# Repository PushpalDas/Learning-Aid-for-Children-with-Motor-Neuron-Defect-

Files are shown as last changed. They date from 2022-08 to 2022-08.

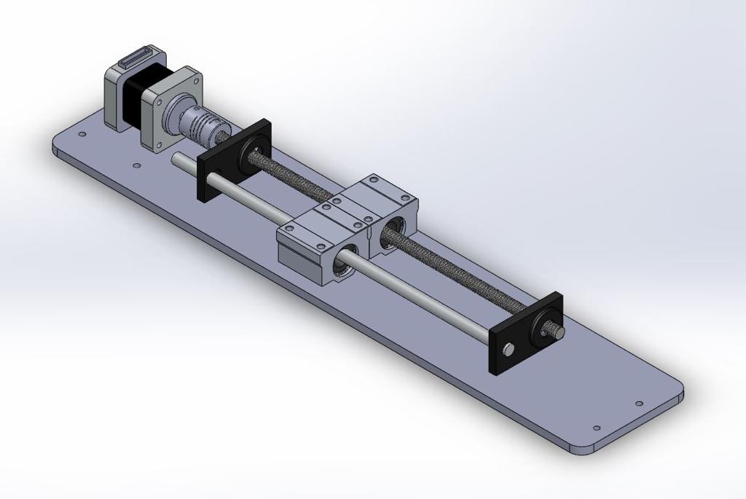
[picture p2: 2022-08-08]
IGES FILES/PHOTO-2022-01-13-23-20-01(11).jpg

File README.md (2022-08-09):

# Learning-Aid-for-Children-with-Motor-Neuron-Defect-
IoT wireless device to help a child write. [Arduino UNO, Stepper Motor, CNC, Bluetooth]

- [CNC Principle Demo - 1 (G-Code)](https://drive.google.com/file/d/1HKVO9aAVFRL1J57MTSo6BBsfIpMUPSG7/view?usp=sharing)
- [CNC Principle Demo - 2 (G-Code)](https://drive.google.com/file/d/1b37IInhLuG2e1p3JiCt-loMVagS_FO2U/view?usp=sharing)
- [CNC Principle Demo - 3 (G-Code)](https://drive.google.com/file/d/1SXlSRdfuU8yRSjG2uXwFo0BQJ_EmRbAA/view?usp=sharing)

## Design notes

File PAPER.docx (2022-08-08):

CNC-based Bluetooth-operated Learning Aid for Neurodiverse Children

P. Dasa, E. Vijayaragavan^b, A. Sarkar^c, S.A.R. Devalan^d, V.P. Dubeye, N. Aryan^f, R. S. Kumar^g A.D. Chatterjee^h

a Department of Electronics & Communication Engineering, SRM Institute of Science and Technology, Kattankulathur, Tamil Nadu 603203, India.

^b Department of Mechanical Engineering, SRM Institute of Science and Technology, Kattankulathur, Tamil Nadu 603203, India.

^c Department of Electronics & Telecommunication Engineering, Jadavpur University, Kolkata, West Bengal 700032, India.

^d Department of Mechanical Engineering, SRM Institute of Science and Technology, Kattankulathur, Tamil Nadu 603203, India.

e Department of Computer Science and Engineering, SRM Institute of Science and Technology, Kattankulathur, Tamil Nadu 603203, India.

^f Department of Computer Science and Engineering, SRM Institute of Science and Technology, Kattankulathur, Tamil Nadu 603203, India.

^g Department of Electronics & Communication Engineering, SRM Institute of Science and Technology, Kattankulathur, Tamil Nadu 603203, India.

^h Department of Computer Science and Engineering,Indian Institute of Engineering Science and Technology, Shibpur, Howrah, West Bengal 711103, India.

Abstract

The main objective of our team was to make an appealing learning assistant for kids who have neurodevelopmental conditions or impaired motor neuron abilities. Although many individuals with autism spectrum disorder today are able to speak, read, and live outside institutions, and some show a decrease in symptoms of the disorder by adulthood, for most of them it is difficult to work full-time or live independently. The common symptoms of such individuals are restricted social communication skills and repetitive sensory-motor behaviours. Our team surveyed some autistic care centres where the specialists said that even in the present age of digitally transforming world when it comes to the education of autistic children, a long-term effective output has not been observed and hence, it could not be predicted whether the kid is getting benefitted from the e-learning materials or not. Our vision was to make a device that will help such a child to learn writing through systematic repetition and stimulating audio-visual signals.

Acknowledgement

Our team would like to express our gratitude to SRM Institute of Science and Technology for the support and guidance . Our team would further express our gratitude to Dr E. Vijayaragavan, for the time, knowledge and constant encouragement she has lent us for making this project. We express our special thanks to Mr Shantanu Sinha, marketing consultant at TCS, for his genuine support and guidance in bringing the product to the market in the future.

Our team extends gratitude to Mrs Sampada Pachaury (https://www.linkedin.com/in/ACoAAAFvnSkB4kaB5wE9D-snUe5Wi9vhkcergZw), Mr Krishna Vedula (https://www.linkedin.com/in/ACoAAACEbJcBGnZhwTKeoU1zOtHO4xEXdkV7bjM) and Mr Aditya Bhatnagar for their diligent guidance and for their support during our research work with Indo Universal Collaboration for Engineering Education (IUCEE) (https://www.linkedin.com/company/indo-universal-collaboration-for-engineering-education/).

We used DigiKey Scheme-it, a free online schematic and diagramming tool, available at https://www.digikey.in/schemeit/home/ for the schematics provided in the paper. We used Inkscape v0.48.5, a free and open-source vector graphics editor primarily used for creating or editing vector graphics, for generating the g-codes. This was made possible by the MI Inkscape extension for GRBL firmware. From https://winder.github.io/ugs_website/ the controlling software for debugging and testing named “Universal Gcode Sender” was downloaded. A similar application for mobile was “G-Code2GRBL” and was downloaded from the Google play store. And most importantly, the GRBL firmware that was programmed into the microcontroller was downloaded from https://github.com/gnea/grbl/.

Content

Sl. No. | Topic | Page Number
1 | Introduction - Fig. 1: Prevalence of Autism Increased by 10%, to 1 in 54 Children by Southwest Autism Research & Resource Center - Fig. 2: Neurotypical Peers are Less Willing to Interact with Those with Autism based on Thin Slice Judgments - Fig. 3: Effect of a normal and regular classroom set up on the concentration and attentiveness of youngsters with autism spectrum disorder: an eye-tracking study | 4 4 5 5
2 | Background | 5

3

Design and Specification

a. Control and Power System
  i. Microcontroller-ATMEGA328P
  ii. CNC V3 shield
  iii. A4988 Stepper motor driver
  iv. NEMA 17 Stepper motor
  v. SG90 Micro Servo
  vi. HC-05 Bluetooth module
b. GRBL control code
c. G-code
d. Application software
- Fig. 4: (a) Logical block of the ATMEGA328P processor; (b) ATMEGA328P pin configuration
- Fig. 5: Pin-configuration of (a) CNC V3 shield; (b) stepper motor driver A4988
- Fig. 6: Configuration of the motors and respective motor drivers
- Fig. 7: (a) HC-05 Bluetooth module; (b) Connecting the Bluetooth module with the controller
- Fig. 8: Physical connections for the entire apparatus. It is to be noted that the CNC V3 shield is inserted onto the Arduino UNO board
- Fig. 9: How the g-code containing information of coordinates is transferred in the system
- Fig. 10: System architecture supporting the application
- Fig. 11: Sequence Diagram for the API
- Fig. 12: Flowchart describing the functioning of the application
- Fig. 13: All paired devices are displayed in the app being developed. Suppose a particular device should be connected, the relevant name must be clicked

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
4 | Implementation - Fig. 14: Perspective view of the model - Fig. 15: Two Dimensional Representation of the Model | 14 15 16
5 | Result and Evaluation - Fig. 16: Graphically Denoted No.of Letters v/s Time by the machine - Fig. 17: Graphically Denoted No.of Letters v/s Temperature of the machine in (Celsius) | 16 17 17
6 | Future Directions | 17
7 | Conclusion | 18
8 | Reflections | 18
9 | References | 19

Introduction

Autism is a term that is used to describe a particular group of people with specific neurodiverse conditions– conditions characterised by lack of ability to interact socially, communication problems and abnormal motor-neuron activity. Autistic Spectrum Disorder is observed in people around the world, irrespective of culture, background, race and ethnicity. “Spectrum” refers to the wide range and severity of symptoms shown by such individuals.

During a study period of 2009-2017, children most of the age from 3-17 were seen diagnosed with disabilities, which includes cerebral palsy, blindness, hyperactivity disorder, autism. Conditions are characterised by contrast in social interaction and communication. Over the study, it has been found that there are numerous causes. It can be due to genetic mutations, having an immediate family member who is autistic, metabolic imbalances, Exposure to heavy metals and environmental toxins, a history of viral infections, fatal exposure to the medications valproic or thalidomide. Subjects show snappy interhemispheric connections in the cerebral cortex.

Autistic kids might not get to the enlightening milestone like their fellow mates. They have difficulty sleeping, irregular food patterns and show signs of heightened anxiety. They often prefer a similar environment with a regular routine. They often show repetitive and restricted motor behaviour. The common motor deficit conditions seen in children with autism are hypotonia, which is characterised by poor muscle strength and disordered spinal reflexes, and motor apraxia, which is a defect in horizontal eye movement. Studies have also found deficits in overall fine motor gross motor development and locomotor skills for such children. These difficulties not only hamper their learning ability but also cause a great deal of anxiety to them.

Statistical data regarding the autistic population

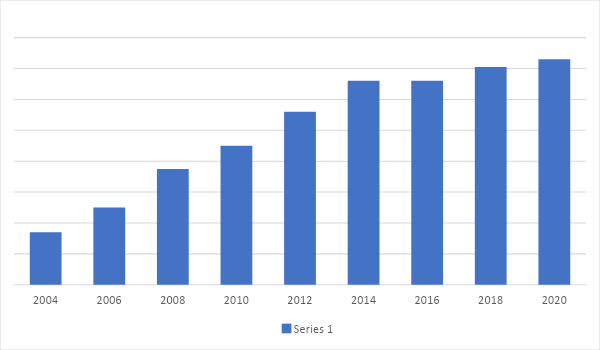
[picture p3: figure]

Fig. 1, Prevalence of Autism Increased by 10%, to 1 in 54 Children by Southwest Autism Research & Resource Center

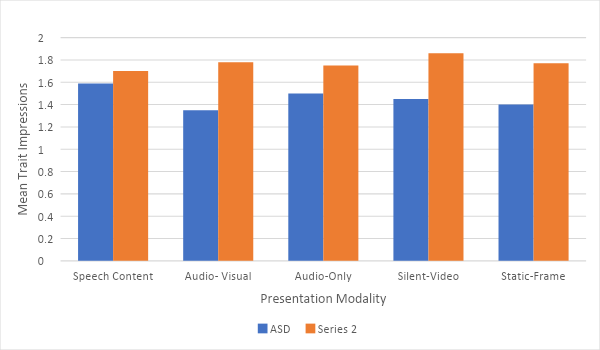
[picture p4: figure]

Fig. 2, Neurotypical Peers are Less Willing to Interact with Those with Autism based on Thin Slice Judgments

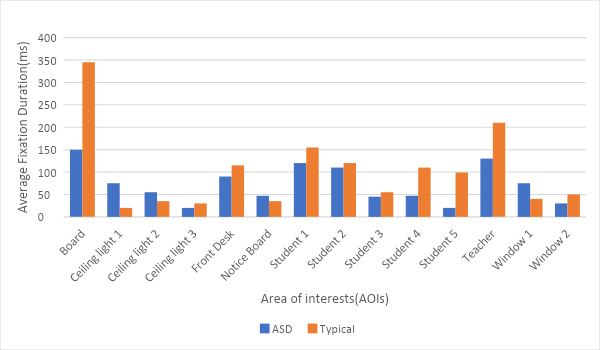
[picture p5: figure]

Fig. 3, Effect of a normal and regular classroom set up on the concentration and attentiveness of youngsters with autism spectrum disorder: an eye-tracking study

Background

The purpose of the present project is to create a link between play and physical therapy, resulting in therapy for such subjects who have writing problems from their very childhood–children who have difficulty distinguishing between 6 and 9, b and d, the alphabetical order, a step from our team to make the basics strong and solve the neurological problem in kids. From the research and surveys performed, it is understood that even in the present era of a digitally-transforming world, when it comes to e-learning platforms and persons with neurodevelopmental disabilities, a proper output is very difficult to ascertain. Given the plethora of application-based learning options, the child would still not receive physical help in actually writing what they have learnt. In special exams, such students would pronounce their answers and a helper would write for them.

Design and Specification

The aim of the project was to make the subject learn to write and correlate what they want to write and what their hand traces on paper by holding a robotic arm in the form of a mini CNC (Computer Numeric Control) machine. The device shall track the pattern of the letter and guide the user to move the hand in the right way to complete the pattern by interactive methods, which is basically the input given from the phone or computer in which the supporting application is installed. The application can be used easily by both the subject(person with a neurological disability) and their mentor. The principle of operation of the CNC machine is the movement of a structure about 3 degrees of freedom, namely the X, Y and Z axes, based on input fed through a computer. They are controlled by stepper motors which can be AC or DC operated. The operations and configurations of the motors like feed, speed, etc. are set with the help of coordinate-like codes.

Control and Power System

Microcontroller-ATMEGA328P

In today's world we have many controllers, so why ATMEGA328P?

ATMEGA328P is one of the most popular because it is cost-effective with exciting features in it. And so due to these features a controller like ATMEGA328P is used to develop Arduino boards. Features like, with a variation on power saving modes it can be used on mobile embedded systems, it has the RISC architecture, as a result of it the program executes quickly, has a timer, the watchdog timer to reset anytime under error on the system with just a human interface and so on. RISC is nothing but a reduced instruction set computer which is a type of architecture that uses a hugely optimised set of instructions than what is found in other architectures. ATMEGA is quite the same as any other microcontrollers in the market. And yes it is well known that there should be a set of instructions in the form of programs provided by us at the instant, without the program nothing is executing the way it should be. As already discussed, there should be a program present in the ATMEGA328 flash memory. This whole execution is done by the controller after the code is dumped and provides an appropriate response. This process is explained in the following steps,

- First step is listing out all the functions that the controller should execute. Functions in programming language can be run at IDE, now here we can use the Arduino IDE too to be discussed later. After the code we need to compile to look for errors.
- The IDE converts the compiled program to the HEX file. The HEX file constitutes the machine code that is executed or written in the controller flash memory.
- Choose the programming device (usually SPI programmer made for AVR controllers) which establishes communication between PC and ATMEGA328P. One can also program ATMEGA328P using the ARDUINO UNO board.
- After the execution all that is needed to do is, disconnecting the programmer, and connecting with the appropriate peripherals for the controller and running the system.

Features

1. The CPU used is an 8-bit AVR with a speed of 1MBPS for 1MHz .
2. There are a total 28 pins present.
3. Operating voltage ranges from +1.8 V to +5.5V.
4. There are 23 programmable I/O lines. For programming this controller, there are three types of communication interface, Master/Slave SPI Serial Interface(17,18,19 PINS).
5. Programmable Serial USART. This controller can be programmed using pins. Peripheral devices such as sensors, memory devices and servos are connected with the help of Two-wire Serial Interface pins.
6. It has ADC Module Of 6 channels, 10-bit resolution ADC. Timer module of two 8-bit counters with Separate Prescaler and compare mode. One 16-bit counter with Separate Prescaler,compare mode and capture mode.
7. There are a total of 1 analog comparator with 6 PWM channels.
8. External Oscillator with 0-4MHz in 1.8V to 5.5V, 0-10MHz in 2.7V to 5.5V, 0-20MHz in 4.5V to 5.5V and an internal oscillator with 8MHz Calibrated Internal Oscillator.
9. Program Memory Type is of flash memory with 32 kilobytes. RAM is 2kbytes Internal SRAM with an EEPROM of 1k bytes.
10. Programmable Watchdog Timer with Separate On-chip oscillator with program lock.
11. 6 major power save modules, Idle, ADC Noise Reduction, Power-save, Power-down, Standby and Extended Standby.
12. The operating temperature is -40°C to +105°C.

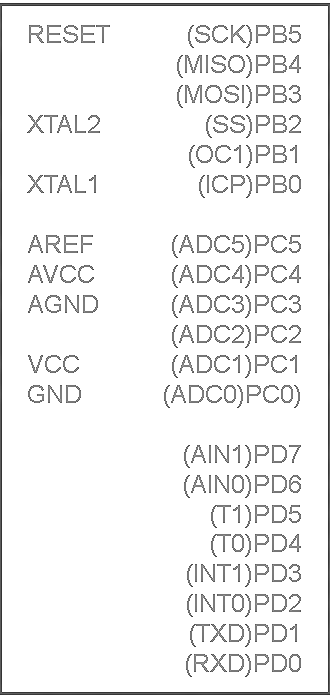
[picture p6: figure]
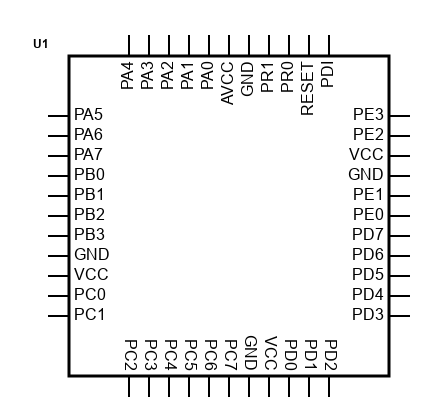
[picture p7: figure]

(a) (b)

Fig. 4, (a) Logical block of the ATMEGA328P processor; (b) ATMEGA328P pin configuration

CNC V3 shield

The CNC V3 shield is made particularly for Arduino based controllers which allows us to build such machines which are used to engrave, like a mini CNC, A 3D printer and so on. It just needs to be fitted on the top of the Arduino with no external wiring required. There are 4 slots for stepper motor drivers in the shield. It supports an input voltage of 12V to 36V. If an input of more than 36V is applied, it will damage the motor drivers.

A4988 Stepper motor drivers

The stepper motor driver, A4988, is a microstepping motor driver fully compatible with the CNC V3 shield. The bipolar stepper motors can be controlled in full, half, quarter, eighth and sixteenth step modes with the help of the drivers. They receive PWM signals from the Arduino and feed the required power according to the motors. The sixteenth step mode is used by inserting 3 jumper caps to cover M0, M1, M2 to improve the precision of the drawing.

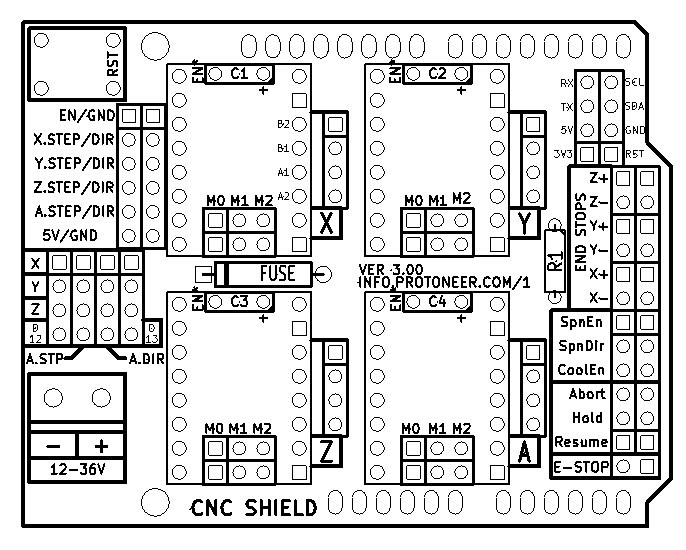
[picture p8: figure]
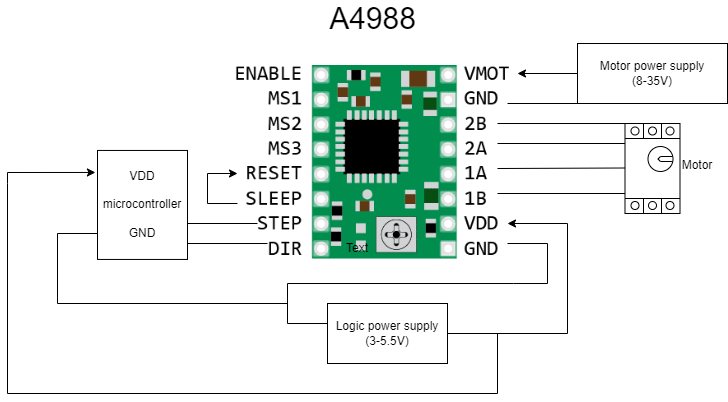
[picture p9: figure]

(a) (b)

Fig. 5, Pin-configuration of (a) CNC V3 shield; (b) stepper motor driver A4988

NEMA 17 Stepper motor

A stepper motor rotates by taking one step at a time, with the energy input given to it by DC and thereby, converts electrical energy into mechanical shaft rotation.

These motors are a vital part of the movement of the x and y axes in analog step values. “NEMA” is the measurement standard provided by the National Electrical Manufacturers Association. NEMA 17 stepper motors are used for this project. A heavier model was used because it could provide large enough torque to rotate the long and heavy metal shaft. For refined models with shorter axes lengths, smaller motors would be sufficient.

SG90 Microservo

Servo motor can be defined as a motor with a specific part, suitable for a closed-loop control system. Servo motors are used in robotics, CNC machining applications and so on. There is the control signal which is the input, it can be analog or digital, representing the final position for the shaft. An encoder serves the role of a sensor with speed and position.

The project deals with the principle of CNC machines and in such cases, nothing is better than the stepper motor to convert instructions into actions. Here the action is depicted as the up and down of the pen for writing and moving to the next consecutive letter.

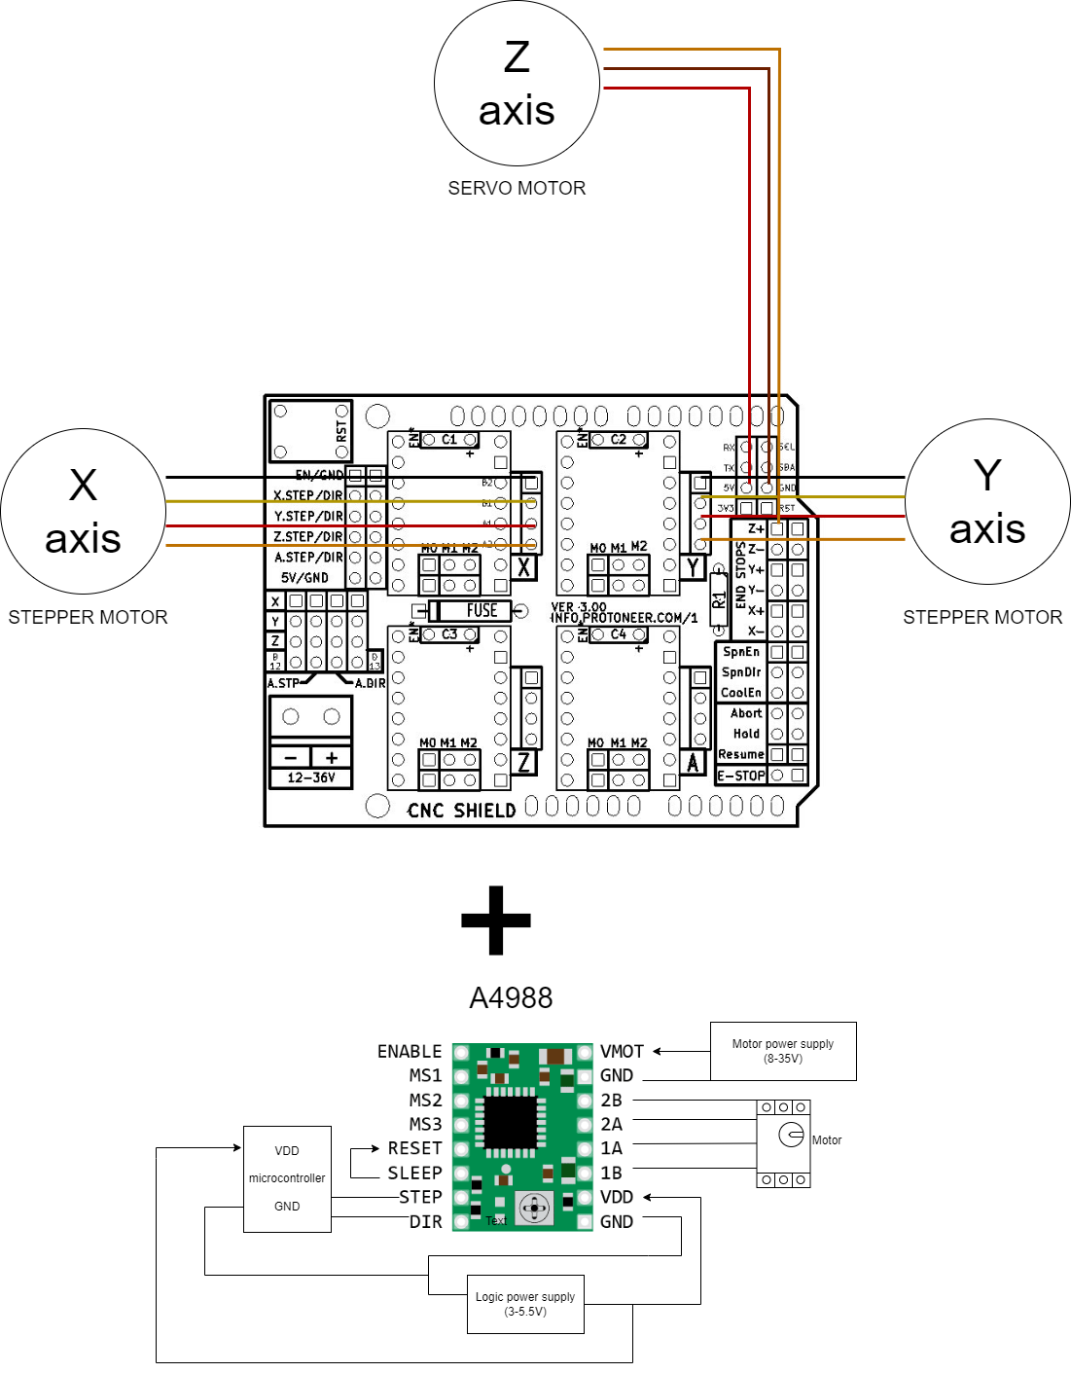
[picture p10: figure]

Fig. 6, Configuration of the motors and respective motor drivers

HC-05 Bluetooth module

Bluetooth HC-05 can be defined as serial communication to communicate with the world of electronics. Connecting to devices with short-range to exchange files. Just the way files are going to get exchanged in the project with a frequency band of 2,4 GHz. HC-05 has a transfer rate of 1Mbps within a range of 10 meters. Input power voltage is 4-6V with a baud rate of 9600, 19200, 38400, 57600, as selected by the user.

The pins of our interest are described below:

1. VCC - Pin which is connected to +5V power supply
2. Ground - Pin which is connected to the ground of the system
3. Tx (Transmitter) - Pin which transfers the wirelessly received data by UART method to the microcontroller
4. Rx (Receiver) - Pin which receives data to be broadcast from the microcontroller.

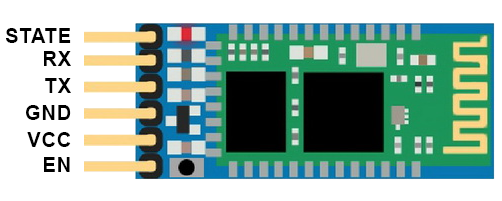
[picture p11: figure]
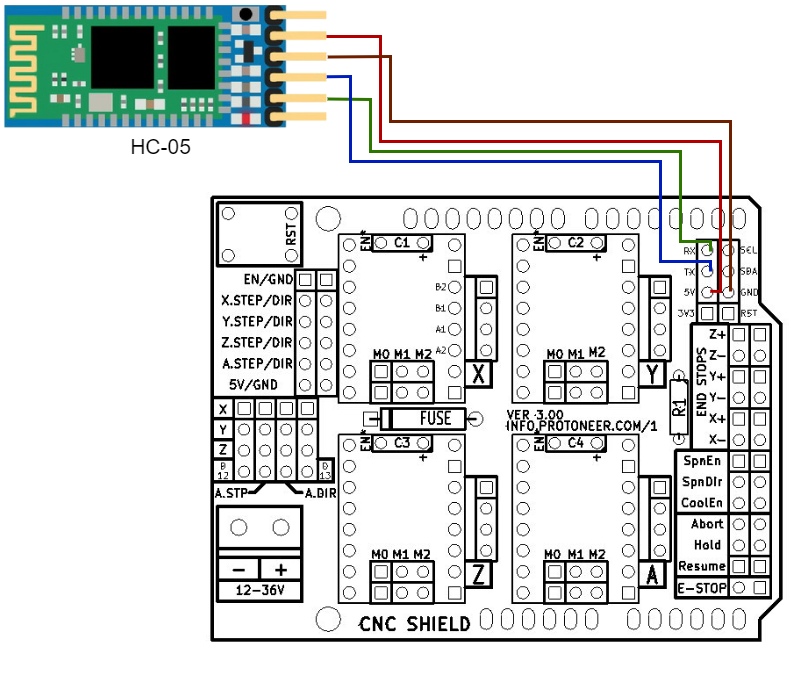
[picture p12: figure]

(a) (b)

Fig. 7, (a) HC-05 Bluetooth module; (b) Connecting the Bluetooth module with the controller

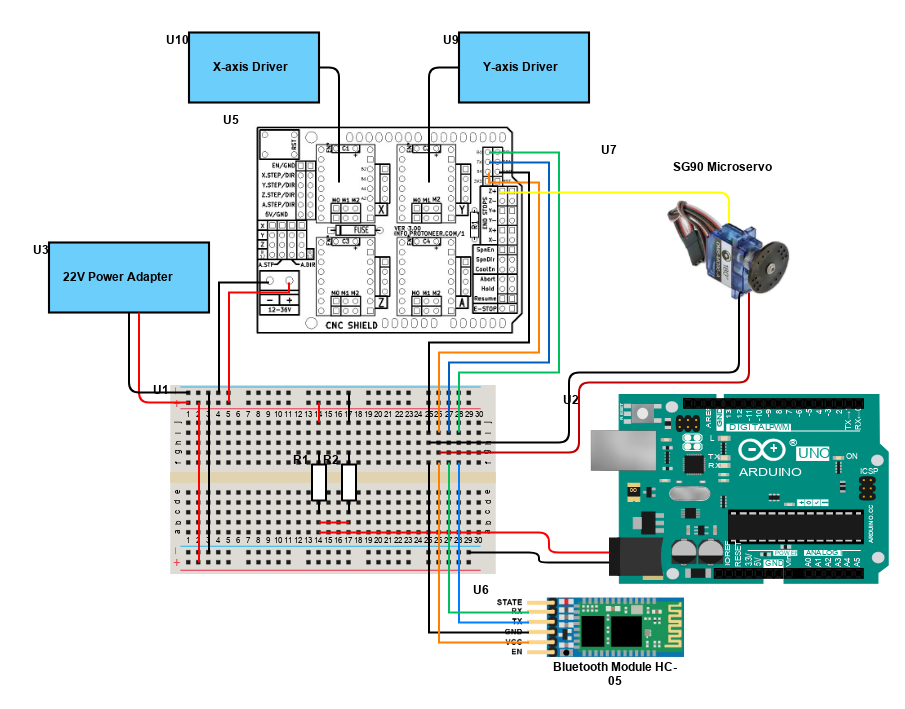
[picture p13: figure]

Fig. 8, Physical connections for the entire apparatus. It is to be noted that the CNC V3 shield is inserted onto the Arduino UNO board

GRBL control code

The shield is GRBL compatible. GRBL is an open-source firmware that is programmed into the Arduino and enables the g-code to be understood by the processor. For the intended purpose, the shield, before running with the stepper motors, needed to have the GRBL firmware installed in the Arduino’s memory. In simple terms , the GRBL uses the motion as the output through the motors via arduino and uses the G-code as an input to run through it.

G-code

G-code simply means “Geometric Code” that can be defined as the language of programming for a Computer Numerical Control machine, a CNC machine. This language is used to set the instruction to the machine to get operated. The speed and the path of the machine can be followed by the GRBL code. From 3D or 2D printing to manufacturing G-code runs the instruction layers formise a precise geometric shape in all dimensions.

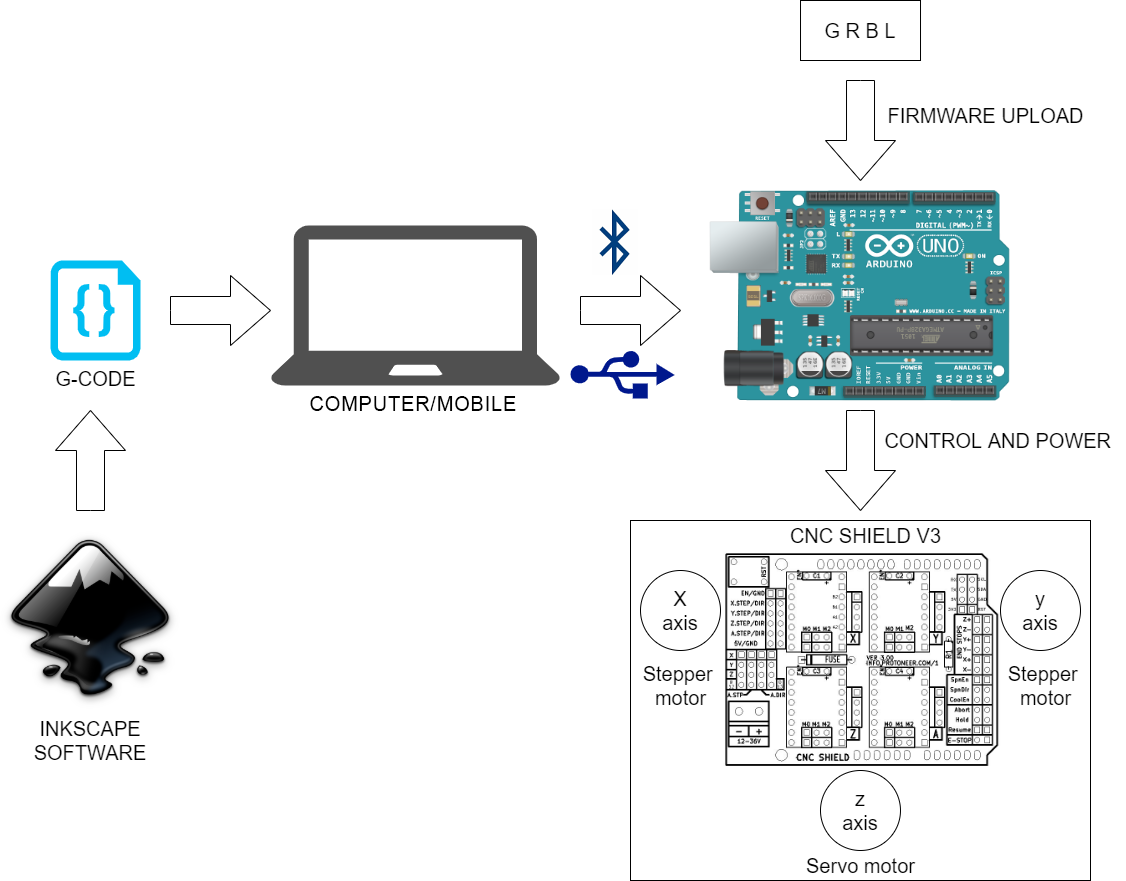
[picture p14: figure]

Fig. 9, How the g-code containing information of coordinates is transferred in the system

Application software

The hardware and its functioning will be controlled by an application running in the mobile phones. It has been assumed that during a teacher-student interaction the hardware is held by the individual with autism/cognitive disability while the mobile application is run by the teacher. A connection will be established over Bluetooth between the app and the actual hardware device. The mobile phone should have the capability to establish Bluetooth connections to use the app.

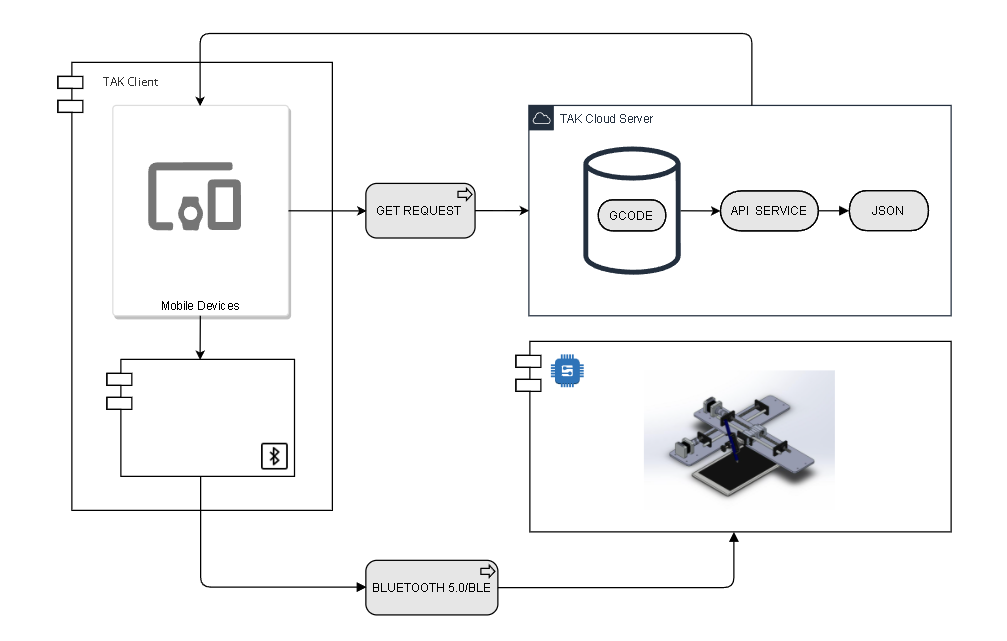
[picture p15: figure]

Fig. 10, System architecture supporting the application

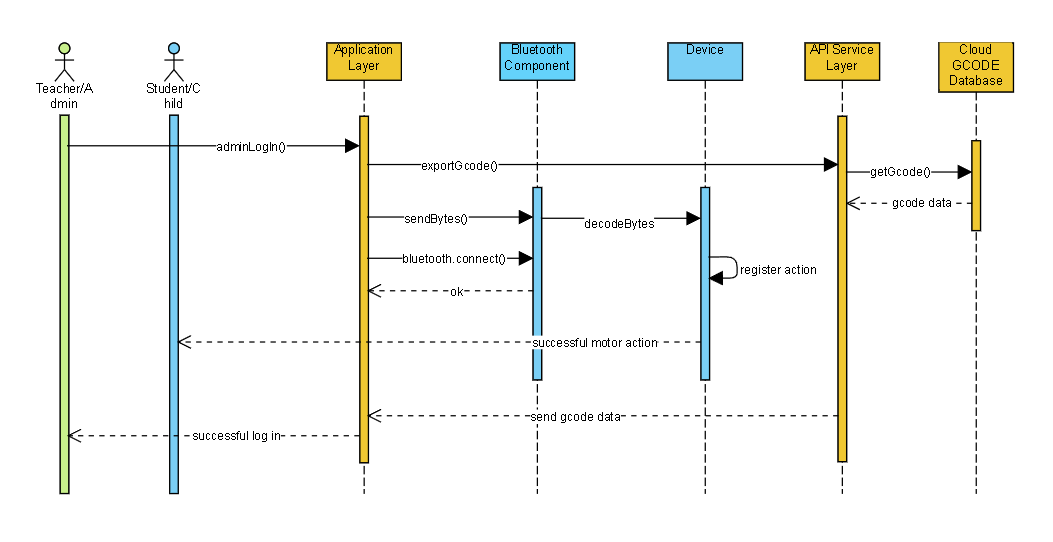
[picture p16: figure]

Fig. 11, Sequence Diagram for the API

Working algorithm, simulation

The official Google Developers site writes -

“To create a connection between two devices, you must implement both the server-side and client-side mechanisms because one device must open a server socket, and the other one must initiate the connection using the server device's MAC address. The server device and the client device each obtain the required Bluetooth socket (https://developer.android.com/reference/android/bluetooth/BluetoothSocket) in different ways. The server receives socket information when an incoming connection is accepted. The client provides socket information when it opens an RFCOMM channel to the server.

The server and client are considered connected to each other when they each have a connected BluetoothSocket on the same RFCOMM channel. At this point, each device can obtain input and output streams, and data transfer can begin”

The hardware Bluetooth device was first paired with the device. The mobile application then scanned through all paired devices to display the paired devices. The user needs to choose the hardware Bluetooth device from them. In the instrument, the hardware Bluetooth device is on the client-side and client-side mechanisms were pre-built. So only the server-side mechanisms need to be implemented,i.e, the mobile application.

Once the Bluetooth connection was established, the next task was to exchange data. In this scenario the exchange of data should be one-way, i.e, instruction signals should be sent from the device running the mobile application to the hardware Bluetooth device.

The hardware part of the product understands only G-code(just like a computer understands only machine language, so whatever high-level programs are written are ultimately converted to sequences 0s and 1s). So the job of the mobile application is to send the G-code corresponding to the relevant action.

The application will have sections like Alphabets, Digits, short sentences, almost everything you and I have been taught when we first went to school. Suppose a kid was learning about the alphabets and the teacher wanted the student to learn “A”. The user interface has buttons corresponding to all the alphabets. When the button displaying “A” was clicked, the corresponding g-code was sent to the hardware Bluetooth device. The Bluetooth accepts the data, decrypts it and a signal is sent to the hardware to trace the alphabet “A”.

The frontend interface will be intuitive and self-explanatory, so that it becomes easy to use and navigate. The home page of the application will be divided into well demarcated sections like alphabets, numbers, etc. Each section will have contents relevant to that topic. We will be using audio visual techniques to capture the attention of the audience. It is said one should pronounce what we read, because it helps in better retention. Thus pre-recorded voices reading aloud a text or an alphabet will be used for better engagement.

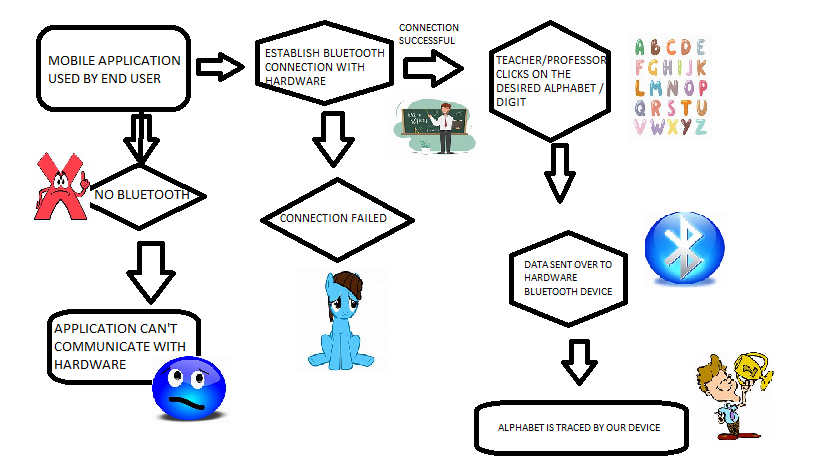
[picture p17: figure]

Fig. 12, Flowchart describing the functioning of the application

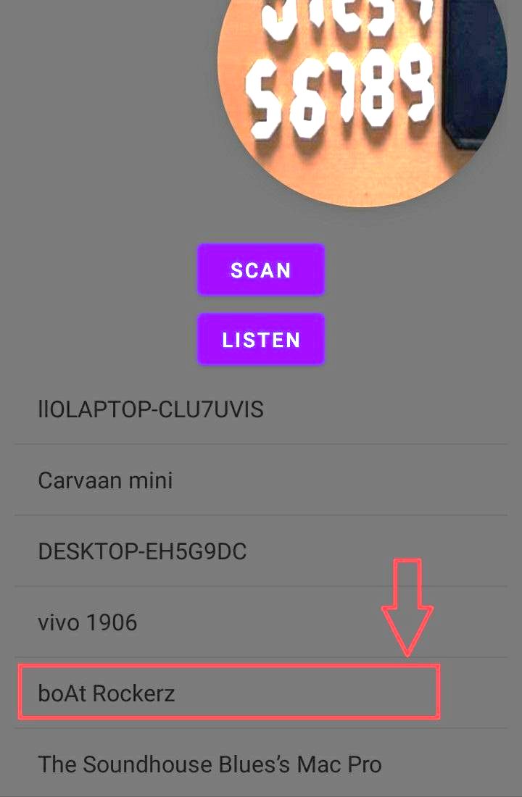
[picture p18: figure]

Fig. 13, All paired devices are displayed in the app being developed. Suppose a particular device should be connected, the relevant name must be clicked

Conclusion

While this is just a prototypic model of the software, there are a lot many improvements that can be added in course of time:

- A Local Area Network can be used for connecting the devices and exchanging data. This is more stable than Bluetooth, and also provides more flexibility. It is possible to control more devices from a single running instance of our application, unlike Bluetooth which allows one-to-one and not multiport connection.
- Speech recognition APIs like Google Translate can be used that allow users to write what they speak.
- The app can be made available in regional languages as well.

Implementation

For the apparatus, a wooden plank was used each for supporting the stepper motors for the x and y axes, along with the metallic shafts and gliders. The plank for the y-axis which held that of the x-axis was made slightly bigger in length to accommodate the microcontroller board and battery that would be fitted later on. Otherwise, both the axes looked similar. Each consisted of a NEMA 17 stepper motor fitted with a flexible coupling, THSL Lead Screw, EN31 Steel rod, linear motion ball bearing, linear bearing bush, radial bearings, block to hold the rod as well as bearings and the axial base. These two axes played a major role in the movement of the main module that is the pen stand. As for the z-axis which consists of a pen fitted to a vertically-moveable wooden block, it had two discrete states characterised by the position of the holder block that either stays down as the pen touches the paper or is lifted up such that there is no contact between the pen and the paper. The pen stand worked on the principle of linear motion provided by the motor and moved with the pen module attached to it. The stand was connected with the x-axis plank and consisted of a micro servo and moveable supportive parts for the rotatory motion of the pen. While the rotation of the motors for the x and y axes was analog–controlled by PWM signals from the respective motor driver (A4988) fitted to a CNC V3 shield atop the Arduino microcontroller board, the binary state of the SG-90 micro servo of the z-axis was controlled by a signal from the Z+ pin of the V3. As the Arduino UNO requires 5-12 volts DC and the CNC V3 requires up to 21 volts to supply the required power to the motors, we used a voltage divider setup using two 1 ohm-½ watt resistors organised on a breadboard. A 22V power adapter supplied regulated DC to the setup, from which 11V was fed to the Arduino UNO board from the node of the divided voltage while the original supply voltage was fed to the shield separately.

After receiving the feed execution command from the GRBL controller application through Bluetooth, the servo system drives each coordinate axis (feed mechanism) for the machine to move accurately in strict accordance with the command necessities and completes the process of the work. Throughout the displacement process, the detection feedback device quickly fed back the measured displacement numerical to the numerical control device for comparison with the command requirement, and then sent the compensation execution command to the servo system at rapid speed unless the measured value was consistent with the required command. There was a warning system to give safety reminders during various operations. In the method of axis displacement, if overtravel happened, the limiting device would send some over travel signals to the controller. Meanwhile, the numerical control system sent alarm signals through the execution and would send stop execution commands to the feed servo system to implement over travel protection. The writing machine works on this principle with the help of g-code as well as the direction of axes.

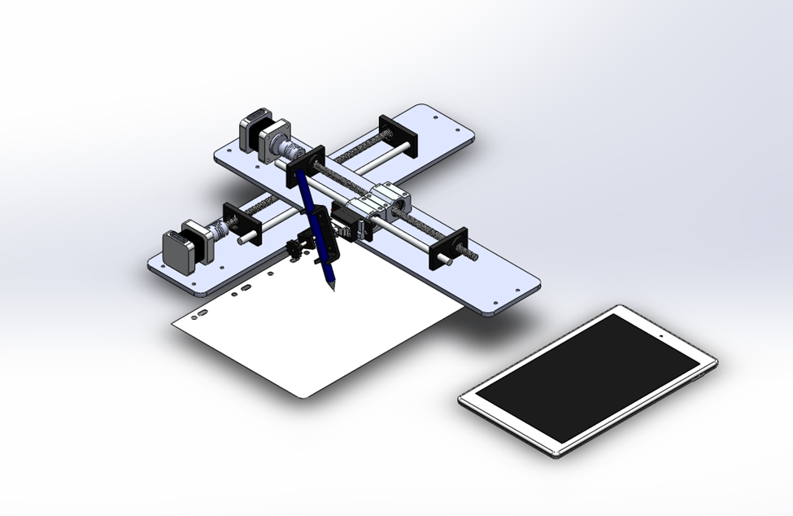
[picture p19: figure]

Fig. 14, Perspective view of the model

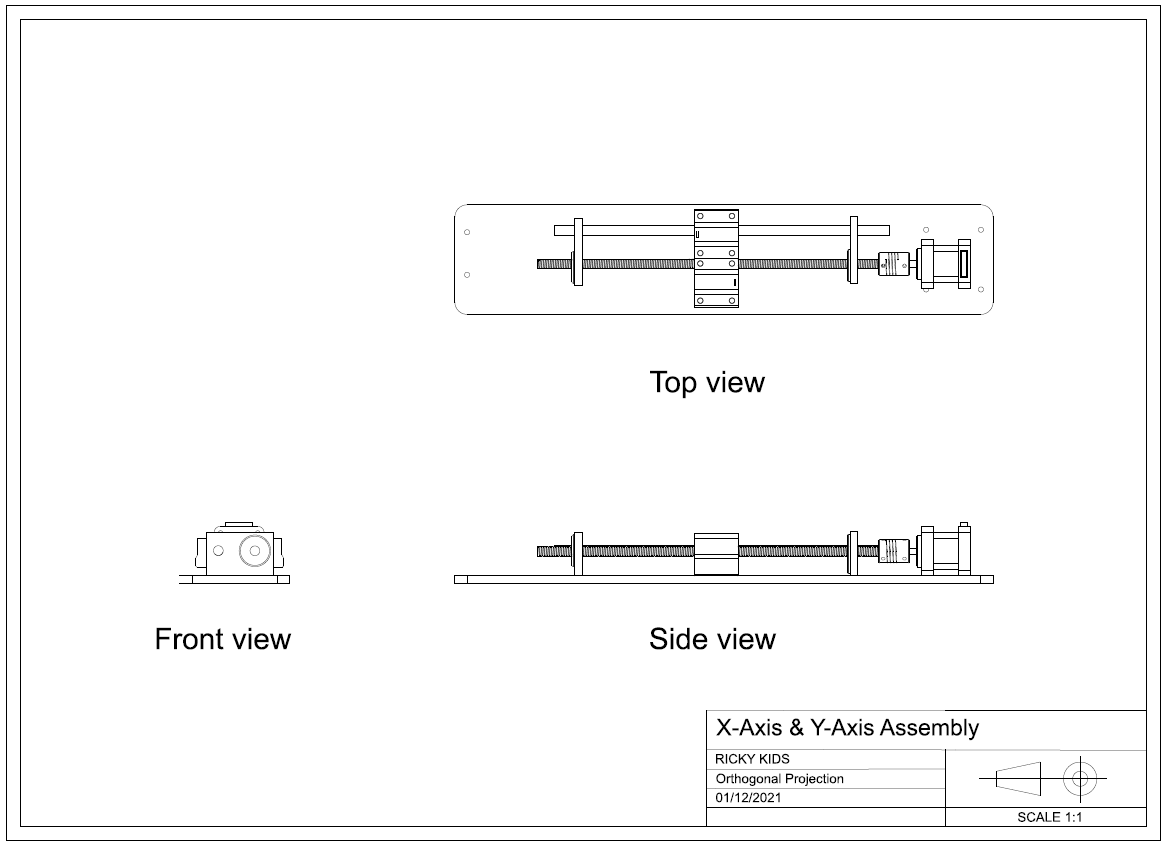
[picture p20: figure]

Fig. 15, Two Dimensional Representation of the Model

Result and Evaluation

The 2-axis setup was working as intended. When a g-code was fed by the “G-Code2GRBL” application in mobile via Bluetooth or by “Universal Gcode Sender” in computer via USB to the microcontroller, the x and y-axis stepper motors rotated just as much to produce the required linear motion in the respective glider. The resolution of the drawing can be scaled up or down by placing jumpers over the appropriate pair of pins underneath the motor driver modules on the CNC V3 shield. While scaling down made the drawing smaller, it benefitted the speed with which it was drawn.

The intention of using this device would be to learn the way the hand moves while writing a specific letter as well as to be able to write words, sentences or paragraphs for people who have motor neuron deficits. The application would be presented in a very appealing manner with audio-visual cues according to inputs from experts that will make the neurodiverse child interested to learn. In institutions and care centres, the application would be linked to tablets, PCs and projectors through WLAN that would allow a single mentor or teacher to cater to multiple subjects.

The present version of the project has a few limitations. It is quite bulky and difficult to carry, even though it is planned to be modular, that is, the different parts can be dismantled and fitted with ease. Writing a single letter would not require such long shafts and heavy motors. Another problem would surface when we try to use the application in one device to control multiple writing machines since Bluetooth provides wireless point-to-point connectivity while we would require a multipoint connection. Apart from that, Bluetooth works on a 2.4 GHz radio band which is an unlicensed frequency used by various wireless devices, therefore, making it susceptible to heavy interference and has a higher chance of corrupting the data. It is also notorious for its range limitations (depending on Bluetooth versions). Those devices that are powered by a battery have an even low range thus making it slightly inconvenient to the operator.

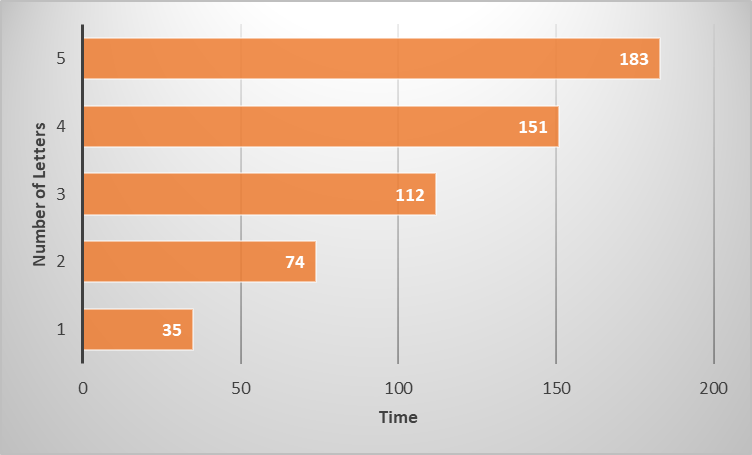
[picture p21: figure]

Fig. 16, Graphically Denoted No.of Letters v/s Time by the machine

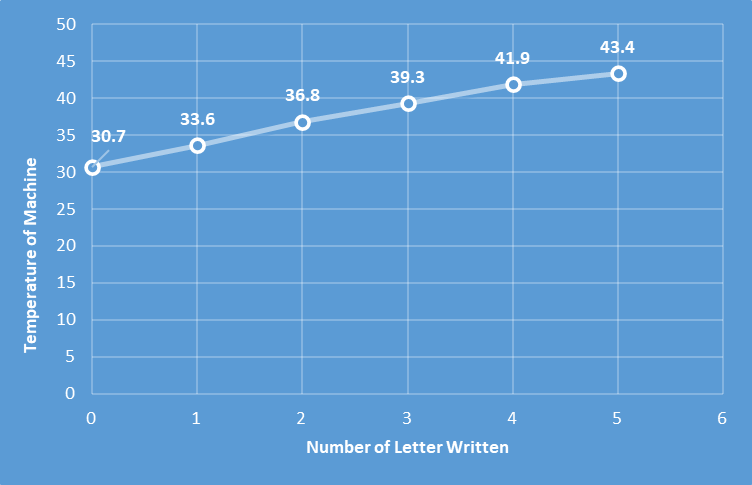
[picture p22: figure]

Fig. 17, Graphically Denoted No.of Letters v/s Temperature of the machine in (Celsius)

Future Directions

In the future, it will be extended in such a way that every single person with neurological problems can be benefitted from our machine. And when we expand and manufacture each and every single component that we are using in our project then we are able to give it in a minimal amount. And when it comes to upgrading this machine, it will be made much easier and more comfortable to be used and for carrying with the users as a portable device, and its efficiency will be enhanced by giving the software updates regularly and troubleshooting the bugs if it is reported by the users with immediate support. The connectivity with the hardware will be more advanced with LTE/WiFi connections. The device will be made compact and easily portable by using small motors, shafts, drivers and custom PCBs for the electronics.

Conclusion

The product could be used as study material as well as a toy for an autistic child, or for persons with impairment in their motor nerves. The automated gliders acting together as a robotic arm would help them to write what they wanted to write by specifying the input simply in the supporting application. In contrast to this topic Make neuroscience to create an impact and make learning easy for every possible human being suffering from neurological problems. This machine is made with a budgeted amount, but as creatives we cannot stop ourselves from exploring and reaching out with the latest drivers, motors and other hardware materials. It is made in such a way to utilise and to make it 100% efficient in this design, in a neat and clean manner. And as it is integrated with the learning application platform it is much easier to use and operate our robotic arm and as it is preloaded with the contents it is much easier for the users to learn from it.

Reflections

Living in the 21st century where children are born and brought up in the age of technologies and the digital world, we must deal with such challenging problems that impair a child’s ability to learn. Often people do have e-learning software but again, we fail to realise how it really affects the kids and also helps the kid to grow and evolve. Growth is a very essential part of life, and growing with just a digital interface is not what our duty is. To make it efficient and worth the time and money they have spent on their development. Through the surveys and the webinar, it has been found that the machine or an artificial hand has scope for neural science in future. It is known that not only autistic kids but many people face neurological problems where if they want to write they cannot do so but our machine, the robotic hand will automatically create an impact on the disabled person. The combination of the concepts of Mechatronic and neuroscience will create a huge impact and make learning very easy for every person suffering from neurological problems. Not only that, it will change the vision of a CNC handwriting machine which is only made for the purpose to print, but here many dots are connected together towards an environmental step in curing the neurological problem of an autistic kid , who has a writing problem. A highly recommended survey was made throughout the survey with a positive response for this TLM (Teaching Learning Material). Many questions were answered positively by the audience regarding the final product.

References

1. Catherine Lord, Mayada Elsabbagh, Gillian Baird, Jeremy Veenstra-Vanderweele. (2018). Autism spectrum disorder. The Lancet, 392(10146), 508-512.
2. Boria S, Fabbri-Destro M, Cattaneo L, Sparaci L, Sinigaglia C, Santelli E, et al. (2009). Intention Understanding in Autism. PLoS ONE 4(5): e5596.
3. Beecham, James & Seneff, Stephanie. (2016). Is there a link between autism and glyphosate-formulated herbicides?. Journal of Autism.
4. Michael L. Matson, Johnny L. Matson, Jennifer S. Beighley. (2011). Comorbidity of physical and motor problems in children with autism. Research in Developmental Disabilities, 32(6), 2304-2308.
5. Pan, C.-Y., Tsai, C.-L., & Chu, C.-H. (2009). Fundamental movement skills in children diagnosed with autism spectrum disorders and attention deficit hyperactivity disorder. Journal of Autism and Developmental Disorders, 39, 1694–1705.
6. Lingam R, Simmons A, Andrews N, et al. (2003). Prevalence of autism and parentally reported triggers in a north east London population. Archives of Disease in Childhood.
7. Scott K. (2020, April 3). Prevalence of Autism Increases by 10%, to 1 in 54 Children. Southwest Autism Research & Resource Center(SARRC). Retrieved February 3, 2022, from https://autismcenter.org/prevalence-autism-increases-10-1-54-children
8. Sasson, N., Faso, D., Nugent, J. et al. (2017). Neurotypical Peers are Less Willing to Interact with Those with Autism based on Thin Slice Judgments. Sci Rep 7, 40700.
9. Banire, B., Al Thani, D., Qaraqe, M. et al. (2021). Impact of mainstream classroom setting on attention of children with autism spectrum disorder: an eye-tracking study. Univ Access Inf Soc 20, 785–795.
10. Autism and Developmental Disabilities Monitoring (ADDM) Network. Centers for Disease Control and Prevention(CDC). Retrieved February 3, 2022, from https://www.cdc.gov/ncbddd/autism/addm.html
11. ATMega328P Microcontroller Pinout, Pin Configuration, Features & Datasheet (components101.com) (https://components101.com/microcontrollers/atmega328p-pinout-features-datasheet)
12. Arduino UNO + Arduino CNC Shield V3.0+A4988 Installation Guide. (2017, April 7). https://osoyoo.com/2017/04/07/arduino-uno-cnc-shield-v3-0-a4988/
13. BluetoothSocket (https://developer.android.com/reference/android/bluetooth/BluetoothSocket). (2021, June 9). Android Developers (https://developer.android.com/guide/topics/connectivity/bluetooth/transfer-data). Retrieved January 27, 2022, from https://developer.android.com/reference/android/bluetooth/BluetoothSocket
14. Transfer Bluetooth data (https://developer.android.com/guide/topics/connectivity/bluetooth/transfer-data). (2021, October 27). Android Developers (https://developer.android.com/guide/topics/connectivity/bluetooth/transfer-data). Retrieved January 27, 2022, from https://developer.android.com/guide/topics/connectivity/bluetooth/transfer-data

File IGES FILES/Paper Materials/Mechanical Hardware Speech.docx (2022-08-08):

HARDWARE

Our team has come up with an innovation to fabricate a device which joins the dots between a hand writing machine and a kid suffering from autism. We have seen the use of printers since ages but no one had ever thought of implementing it as a cure of such neurological problems. So we are here with the solution of replacing the axis of the pen holder with a robotic slider for the kid to put his/her hand over it and learn to write alphabets and numbers. The flexible nib pen is mounted on a servo motor which rotates the tip onto the writing surface, taking care of the third axis.

PEN STAND

The pen stand works on the principle of linear motion provided by the motor and moves with the pen module attached with it. The pen stand is connected with the x axis plate which is operated in contact along the y axis plate of the machine. The pen stand consists of a stepper motor and supportive parts for the rotatory motion of the pen.

X AND Y AXIS

The X and y axis also works on the principle of linear motion and rotation.

To move both the axis, we have used a stepper motor which is more efficient than the servo motor to work on with the coupling and rotating the shafts with the gliders in it. The x and y axis commonly consist of stepper motors in it and small parts like ball bearing, coupling, nuts and shaft of both the screw and a plain type are assembled with blocks supporting the motors and providing a rotary motion over it . The x and y axis plays a major role in the movement of the main module that is the pen stand.

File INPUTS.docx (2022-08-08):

We started with a vision of making the device a low cost one so that it is affordable enough for NGOs, public autistic centres or schools or even parents to purchase. Our team has tried to develop the device prototype with a budgeted amount, but as creatives, we cannot stop ourselves from being bound to it and experimenting with different hardware materials and different ways to build it. We have an estimated research and development cost of about 10,000 rupees for the prototype. But it is possible that if we replace the whole microcontroller boards and ICs like the Arduino, the motor driver and the bluetooth module and integrate everything in a much compact circuit, we can cut down heavily on costs. We have also made it a point to scale down the device and make it portable for children to carry it like a tiffin box. Such scaling will further reduce costs. With more research and optimization, and with mass production, we can very well have it under 5000 apiece.

our application or software is basically like a e-learning platform

for the autistic child. That's why we are including both

visual and sound effects in the software, with the letters and any learning contents

which can stimulate the child , to get the interest to learn from the application

and at the same time they can implement it practically

in the front end the teacher/ an user will get an option for

choosing the content from the application, lets take an

example if the letter a is selected then the animation and the visual

effects like " a for apple " will be displayed to the kid and as we said, it will

be fascinating and interesting for the kid to see it, then if the

kid is ready to write the letter, then the teacher had an option with our

application to turn on the robotic hand which will make the kid to write and

learn at the same time.

In the back-end, the teacher will have a list of student devices

connected with their device in a Wireless LAN support, where they had an option to

monitor each and every student and see how they learn. If a teacher selects

'A' for one student and 'B' for another, then they both can see the visuals of

the respective content that their teacher has assigned to them .

Then once the kid is ready, the teacher can start the device that will

make them to write physically. So the students can learn visually and

they can write on their own with the help of our machine.

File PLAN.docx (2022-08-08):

1)Ongoing project - TOYS FOR AUTISTIC KIDS (IUCEE runner up)

TEAMMATES🔰

abhisrkr007@gmail.com

panakalaryan@gmail.com

aheldc@gmail.com

dvedprakash2001@gmail.com

as5539@srmist.edu.in

sr7210@srmist.edu.in

Professor in charge - Dr E Vijayaragavan.

PAPER SUBMISSION AND PROTOTYPE BY 31st JAN‼️🔰

DRIVE LINK- https://drive.google.com/drive/folders/190aY_5P2yA6ZHOS_uLnlObiHMA3uP8AD?usp=sharing

CURRENT STATUS

- CONCEPT MODEL- 55% WORKED
- ONGOING RESEARCH FOR CONCEPT MODEL- https://docs.google.com/document/d/1-q_w6wIKORlfVaB0msR-yNz3cRTPhaECiiF_atIIraE/edit?usp=sharing

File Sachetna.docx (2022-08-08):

INTRODUCTION and why we are here

Dr E Vijayaragavn sir-

Me-A very good evening to everyone present here , our respected mentor Vijayaragav sir , Nilanjana ma'am , Shantunu sir and my fellow team leads .I am Pushpal Das, currently pursuing bachelor in technology in electronics and communication engineering third year from SRM Institute of science and technology.I have my interest in embedded system analysis, digital electronics, communication, integrated circuits, and information technology products.I am a believer in practical observations and working hand-on projects and research works. I lead a team of 9 members named RICKY KIDS, where we have a hub of projects and research works assigned by respected professors. I am currently working on four projects and five research work-publication, and competitions followed BY.

Abhishek Sarkar-

Ahel Das Chatterjee-

Suriya-

Our presentation

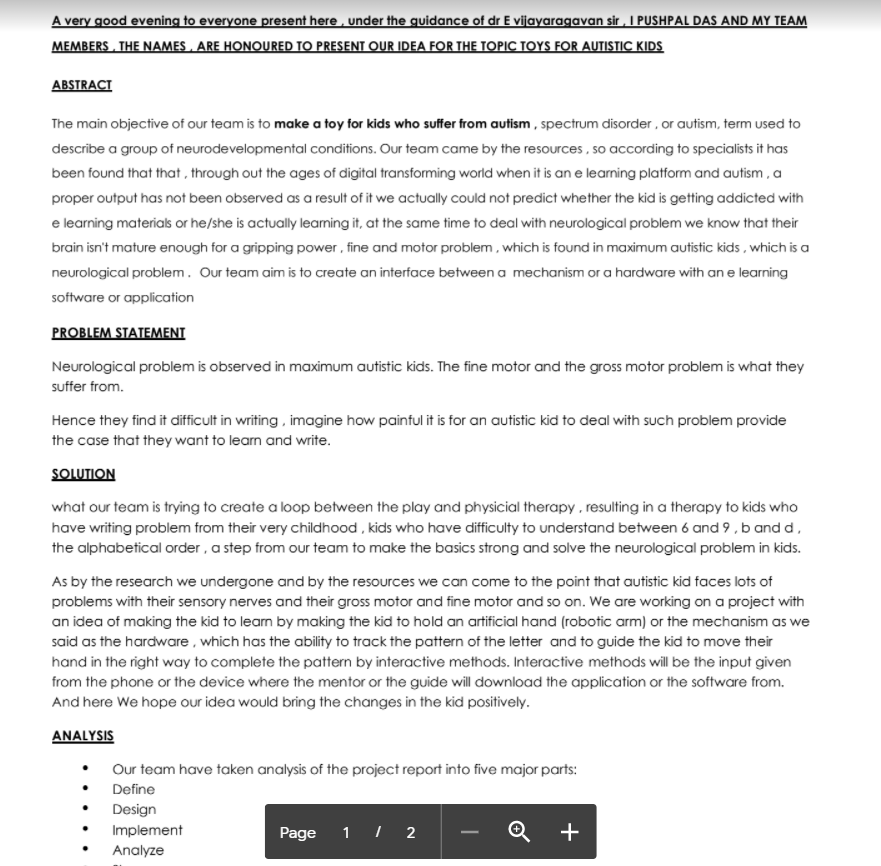
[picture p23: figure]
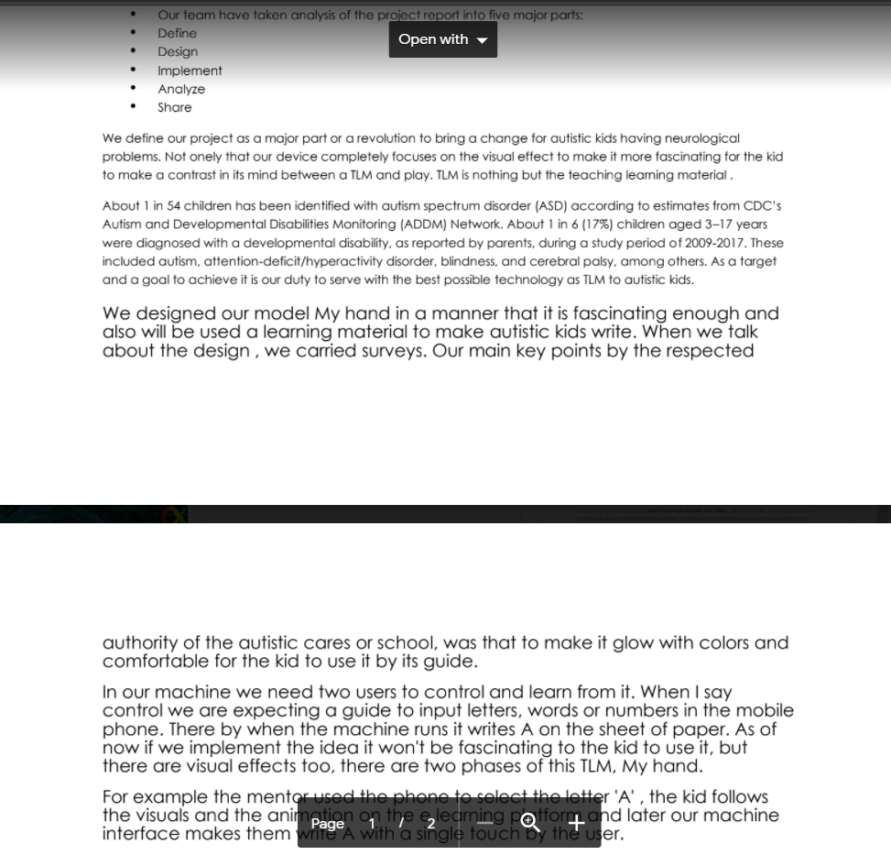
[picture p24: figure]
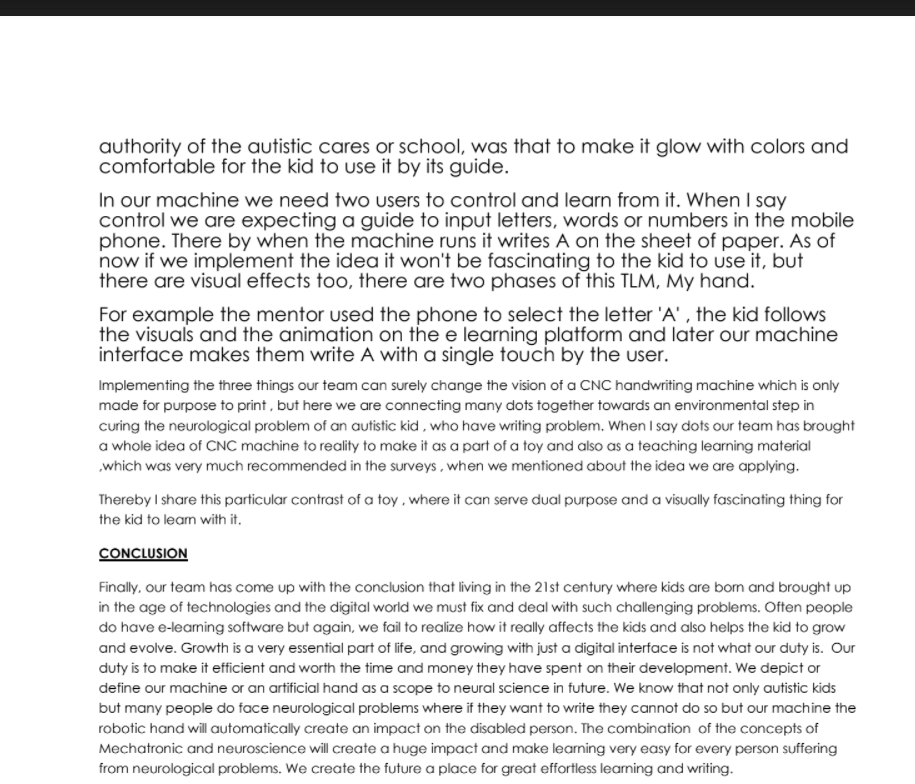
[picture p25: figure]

@me

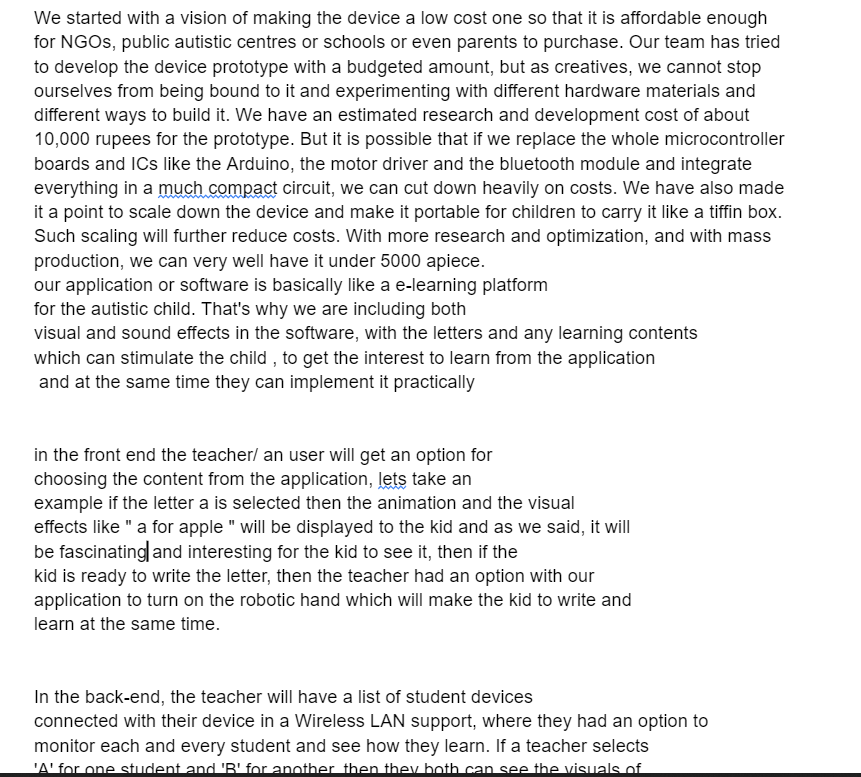
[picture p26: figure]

aheldc@gmail.comAHEL

@me-Starting , Abstract , problem statement , solution . Analysis.

as5539@srmist.edu.in-HARDWARE PART!

aheldc@gmail.com-SOFTWARE PART!

abhisrkr007@gmail.com-DESIGN CONSTRAINTS!

PRESENTATION-https://drive.google.com/file/d/1DHgfut6E9dQgXVce7BeZ3q5r5HDMmfDi/view?usp=sharing

What is the app all about? How cognitively can it helped ?

aheldc@gmail.comAHEL

Why he is on board?What work made you over here?- Mr Shantanu Sinha

What is our marketing strategy?

vijayare@srmist.edu.inVIJAYARAGAVAN SIR

@me

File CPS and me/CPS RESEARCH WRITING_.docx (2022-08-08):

Title page-

CNC-based Bluetooth-operated Learning Aid for Children with Autism or Dyslexia.

Abstract-

The main objective of our team is to make a toy for kids who suffer from autism, spectrum disorder, or autism, a term used to

describe a group of neurodevelopmental conditions. Our team came by the resources, so according to specialists it has

been found that that, throughout the ages of digital transforming world when it is an e-learning platform and autism, a

proper output has not been observed as a result of it we actually could not predict whether the kid is getting addicted to

e-learning materials or he/she is learning it in real-time, at the same time to deal with the neurological problem we know that there

the brain isn't mature enough for a gripping power, fine and motor problem, which is found in maximum autistic kids, which is a

neurological problem. Our team aim is to create an interface between a mechanism or hardware with an e-learning

software or application.

Acknowledgement-

We would like to express my deep and sincere gratitude to our research supervisor, Dr. E Vijayaragav sir , Professor and Head of , SRM Institute of science and Technology, Chennai for giving me the opportunity to do research and providing invaluable guidance throughout this research. His dynamism, vision, sincerity and motivation have deeply inspired me. He has taught me the methodology to carry out the research and to present the research works as clearly as possible. It was a great privilege and honour to work and study under his guidance. I am extremely grateful for what he has offered me. I would also like to thank him for his friendship, empathy, and great sense of humour.

Our team would further express our gratitude to Nilanjana Rambothu ma’am, Founder and Director of Sunshine Autism Care and consultant RCI holder in Special education (ASD) , for the time she has contributed to this project and for her constant encouragement. I express my special thanks to Mr Shantanu Sinha,marketing consultant with 24 years of experience in the Information Technology Industry with exposure in a wide range of technology, solution design and business consulting roles in TCS. for his genuine support throughout this research work.

Our team extended its gratitude to Sampada Pachaury (https://www.linkedin.com/in/ACoAAAFvnSkB4kaB5wE9D-snUe5Wi9vhkcergZw) ma’am , Krishna Vedula (https://www.linkedin.com/in/ACoAAACEbJcBGnZhwTKeoU1zOtHO4xEXdkV7bjM) sir and Aditya Bhatnagar sir for their diligent guidance and for their support during my research work with Indo Universal Collaboration for Engineering Education ( IUCEE ) (https://www.linkedin.com/company/indo-universal-collaboration-for-engineering-education/).

Finally, our team thanks go to all the people who have supported me to complete the research work directly or indirectly.

Table of contents-

Introduction

I. Autism

Autism and Developmental Disabilities Monitoring (ADDM) Network | CDC (https://www.cdc.gov/ncbddd/autism/addm.html)

Autism is a term which is used to describe a particular group of people suffering from neurotypical conditions. Conditions which we can characterise by properties like being able to interact socially and communication problems. Autistic Spectrum Disorder is observed in people around the world, irrespective of culture, background, race and ethnicity.Repetitive interests of behaviour , the pattern of the restricted individual is observed in people with ASD, Autistic Spectrum Disorder.

During a study period of 2009-2017, children most of the age from 3-17 were seen diagnosed with disabilities, which includes cerebral palsy, blindness, hyperactivity disorder, autism.

II. How and why does it occur?

Conditions which are characterised by a contrast in social interaction and communication.Over the study it has been found that there are numerous causes. First of all it can be due to genetic mutations, having an immediate family member who is autistic. Fragile X syndrome and other genetic disorders being born to older parents, low birth rate. Metabolic imbalances. Exposure to heavy metals and environmental toxins. A history of viral infections , fatal exposure to the medications valproic or thalidomide.

III. Statistical data regarding autism population
IV. Difficulties faced by these children in learning

Children with autism might not reach the developmental milestone as their peers. Repetitive behaviour is observed in maximum such cases. They have difficulty sleeping and irregular food patterns.

ASD children find the change in themselves in a stressful manner.They often prefer similar environment with a regular routine, due to their

Sensory aspect of their diagnosis, information processing and behavioural aspect too. Now these small changes like repetitive and restricted interests, heightened anxiety can be stressful.

I. Problem statement

Neurological problem is observed in maximum autistic kids. The fine motor and the gross motor problem is what they

suffer from.

Hence they find it difficult in writing , imagine how painful it is for an autistic kid to deal with such problem provide

the case that they want to learn and write.

II. Brief about the problem

The main objective of our team is to make a toy for kids who suffer from autism , spectrum disorder , or autism, term used to

describe a group of neurodevelopmental conditions. Our team came by the resources , so according to specialists it has

been found that that , throughout the ages of digital transforming world when it is an e learning platform and autism , a

proper output has not been observed as a result of it we actually could not predict whether the kid is getting addicted with

e learning materials or he/she is actually learning it, at the same time to deal with neurological problem we know that their

brain isn't mature enough for a gripping power , fine and motor problem , which is found in maximum autistic kids , which is a

neurological problem .

III. Aim

Our team aim is to create an interface between a mechanism or a hardware with an e learning

software or application

Methodology

INTRODUCTION

our team is trying to create a loop between the play and physicial therapy , resulting in a therapy to kids who

have writing problem from their very childhood , kids who have difficulty to understand between 6 and 9 , b and d ,

the alphabetical order , a step from our team to make the basics strong and solve the neurological problem in kids.

As by the research we undergone and by the resources we can come to the point that autistic kid faces lots of

problems with their sensory nerves and their gross motor and fine motor and so on. We are working on a project with

an idea of making the kid to learn by making the kid to hold an artificial hand (robotic arm) or the mechanism as we

said as the hardware , which has the ability to track the pattern of the letter and to guide the kid to move their

hand in the right way to complete the pattern by interactive methods. Interactive methods will be the input given

from the phone or the device where the mentor or the guide will download the application or the software from.

And here We hope our idea would bring the changes in the kid positively.

A)Design and specifications

I. Concept sketching
II. Design constraints.
III. A rough sketch of the model

B)Control and Power System

I. Analysis
- Microcontroller used

### ATMEGA328P

In todays world we have many controllers, then why ATMEGA328P?

ATMEGA328P is one of the popular because it is cost effective with exciting features in it.Even Arduino boards are developed on such a controller because of the features.

Features like , with variation on power saving modes it can be used on mobile embedded systems, it has the RISC architecture, as a result of it the program executes quickly, has a timer, the watchdog timer to reset anytime under error on the system with just a human interface and so on.RISC is nothing but a reduced instruction set computer which is a type of architecture which used hugly optimised set of instruction than what found in other architectures.

ATMEGA is quite the same as any other microcontrollers in the market.And yes we all know there should be a set of instructions in the form of programs provided by us at instant, without the program nothing is executing the way it should be.As already discussed , there should be a program present in the ATMEGA328 flash memory.This whole execution is done by the controller after the code is dump and provides appropriate response.

Lets see how we should extract the the process into the following steps,

- First step is we need to list out all the functions that the controller should execute. Functions in programming language can be run at IDE, now here we can use the Arduino IDE too to be discussed later. After the code we need to compile to look for errors.
- The IDE converts the compiled program to HEX file. The HEX file constitutes the machine code that is executed or written in the controller flash memory.
- Choose the programming device (usually SPI programmer made for AVR controllers) which establishes communication between PC and ATMEGA328P. You can also program ATMEGA328P using the ARDUINO UNO board.
- After the execution all we need to do is , to disconnect the programmer, and connect with the appropriate peripherals for the controller and run the system.

FEATURES

1. The CPU used is an 8-bit AVR with a speed of 1MBPS for 1MHz .
2. There are a total 28 pins present.
3. Operating voltage ranges from +1.8 V TO +5.5V.
4. Number of programmable I/O lines is 23. There are three types of communication interface, Master/Slave SPI Serial Interface(17,18,19 PINS), Can be used for programming this controller.
5. Programmable Serial USART. Pins can be used for programming this controller. Two-wire Serial Interface pins are used to connect peripheral devices like memory devices, sensors and servos.
6. It has ADC Module Of 6 channels, 10-bit resolution ADC. Timer module of two 8-bit counters with Separate Prescaler and compare mode. One 16-bit counter with Separate Prescaler,compare mode and capture mode.
7. There are a total of 1 analog comparator with 6 PWM channels.
8. External Oscillator with 0-4MHz in 1.8V to 5.5V, 0-10MHz in 2.7V to 5.5V, 0-20MHz in 4.5V to 5.5V and an internal oscillator with 8MHz Calibrated Internal Oscillator.
9. Program Memory Type is of flash memory with 32 kbytes. RAM is 2kbytes Internal SRAM with an EEPROM of 1k bytes.
10. Programmable Watchdog Timer with Separate On-chipOscillator with program lock.
11. 6 major power save modules, Idle, ADC Noise Reduction, Power-save, Power-down, Standby and Extended Standby.
12. Operating Temperature is -40°C to +105°C.


- Motor Driver used

CNC SHEILD V3


The shield used CNC Shield v3, is made for particularly arduino based controllers which allows us to build such machines which is used to engrave, like a mini CNC, A 3D printer and so on.It just needs to be fit on the top of the arduino with no external wiring required. As we can see there are a total of 4 slots for stepper motor drivers in the shield. The shield before running with the stepper motor needs to install the GRBL firmware to enable the controller to work in parallely with the shield.

The shield supports a input voltage of 12V to 36V.If we put an input of more than 36V it will burn the motor drivers. Motor drivers like A4988, DRV8825. A4988 is used in the project.Features:-

- As it is known that it is particularly made for building 3D printers or we can just simply say any project where we need to control a stepper motor.
- Arduino compatible shield which allows the user to connect 4 stepper motor with the latest arduino shield version 3.10
- The shield is GRBL compatible , GRBL is an open source firmware which is programmed into the arduino and enables the GCODE to run through it , we will see a bit about the GCODE later on.
- The shield does support PWM signal as a result of which the spindle is way easier with 4 axis , X,Y,Z,A.
- It is a compact shield with coolant ability, even it supports a removable A4988 stepper driver which is very well compatible with the shield.
- The shield runs on 12-36V DC.

Stepper drivers

A4988 or DRV8825 compatible stepping driver

The stepping driver, A4988 has a built in translator for being easily operated , a complete microstepping motor driver. The drivers can be used to control bipolar motors in full, half, quarter, eigth and sixteenth step modes.


- Motors used

Stepper motor.

A stepper motor can be defined as a DC motor which does not rotate in a continuous motion. It rotates by taking one step at a time, with the energy iput given to it. Thereby a stepper motor converts electrical energy into mechanical shaft rotation.

The project deals with the principle of CNC machines and in such cases nothing is better than the stepper motor. Stepper motors are a vital part in the case of moving the x,y,z axis. Stepper motors are built unique to hold the position and at a fixed interval. Thereby it is often seen that the stepper motor is used in the field of robotics and printers particularly.Stepper motors do come in a variety. Some preferable stepper motors are the NEMA series , NEMA is nothing but the measurement standard provided by the National Electrical Manufacturers Association.NEMA 14, NEMA 17, NEMA 23, and NEMA 24 are few sizes.Larger the frame does not conclude increase in torque.

Servo motor.

Servo motor can be defined as a motor with a specific part, suitable for a closed loop control system. Servo motors are used in robotics, CNC machining applications and so on. There is the control signal which is the input, it can be analog or digital, representing the final position for the shaft. A encoder serves the role of a sensor with speed and position.

The project deals with the principle of Computer Numeric Control (CNC) machine and in such cases nothing is better than the stepper motor to convert instructions into actions. Here action is depicted as the up and down of the pen for writing and moving to the next consecutive letter.

- Wireless module

Bluetooth HC-05,

Bluetooth HC-05 can be defined as a serial communication to communicate with the world of electronics. Connecting to devices with short range to exchange files. Just the way files are going to get exchanged in the project with a frequency band of 2,4 GHz. HC-05 has a transfer rate of 1Mbps within a range of 10meters. Input power voltage is 4-6V with a baud rate of 9600, 19200, 38400, 57600, as selected by the user.


EN(Enable)- Pin which is used to set the data mode at command mode

VCC - Pin which is connected to +5V power supply.

Ground - Pin which is connected to the coround of the system.

Tx (Transmitter) - Pin which is used to transmits the received data

Rx (Receiver) - Pin which is used for broadcasting data.

State -Pin which is used to check if the bluetooth module is working properly or not.

II. Design constraints
III. Overview

C)Software

I. Introduction
II. Layers
  A. SYSTEM ARCHITECTURE DIAGRAM


B. SEQUENCE DIAGRAM


III. Algorithm
IV. simulation
V. Design constraints
VI. Database
VII. Overview

Implementation

I. Procedure
II. Specification
III. Aim & design

Evaluation

I. Result
II. Evaluation
III. Features
IV. How it can improve the learning capabilities
V. User case studies
VI. Limitations

Future Work

I. Compact
II. Portable

Conclusions

our team has come up with the conclusion that living in the 21st century where kids are born and brought up

in the age of technologies and the digital world we must fix and deal with such challenging problems. Often people

do have e-learning software but again, we fail to realize how it really affects the kids and also helps the kid to grow

and evolve. Growth is a very essential part of life, and growing with just a digital interface is not what our duty is. Our

duty is to make it efficient and worth the time and money they have spent on their development. We depict or

define our machine or an artificial hand as a scope to neural science in future. We know that not only autistic kids

but many people do face neurological problems where if they want to write they cannot do so but our machine the

robotic hand will automatically create an impact on the disabled person. The combination of the concepts of

Mechatronic and neuroscience will create a huge impact and make learning very easy for every person suffering

from neurological problems. We create the future a place for great effortless learning and writing.

Reflections

Living in the 21st century where kids are born and brought up in the age of technologies and the digital world we must fix and deal with such challenging problems. Often people do have e-learning software but again, we fail to realise how it really affects the kids and also helps the kid to grow and evolve. Growth is a very essential part of life, and growing with just a digital interface is not what our duty is. Our duty is to make it efficient and worth the time and money they have spent on their development.Through out the surveys and webinar it has been found that the machine or an artificial hand as a scope to neural science in future. It is know that not only autistic kids but many people do face neurological problems where if they want to write they cannot do so but our machine thea robotic hand will automatically create an impact on the disabled person. The combination of the concepts of Mechatronic and neuroscience will create a huge impact and make learning very easy for every person suffering

from neurological problems. Not only that, it will change the vision of a CNC handwriting machine which is only

made for purpose to print , but here many dots are connected together towards an environmental step in

curing the neurological problem of an autistic kid , who has a writing problem. A highly recommended survey was made throughout the survey with a positive response for this TLM(Teaching Learning Material). Many questions were answered positively from the audience regarding the final product.

Reference

Trends over time in the number of children with autism according to the... | Download Scientific Diagram (researchgate.net) (https://www.researchgate.net/figure/Trends-over-time-in-the-number-of-children-with-autism-according-to-the-IDEA-and-in-the_fig7_291186663)

Europe PMC (https://europepmc.org/article/med/12876158)

Prevalence of Autism Increases by 10%, to 1 in 54 Children | Southwest Autism Research & Resource Center (SARRC) (autismcenter.org) (https://autismcenter.org/prevalence-autism-increases-10-1-54-children)

Neurotypical Peers are Less Willing to Interact with Those with Autism based on Thin Slice Judgments | Scientific Reports (nature.com) (https://www.nature.com/articles/srep40700)

Impact of mainstream classroom setting on attention of children with autism spectrum disorder: an eye-tracking study | SpringerLink (https://link.springer.com/article/10.1007/s10209-020-00749-0)

Autism and Developmental Disabilities Monitoring (ADDM) Network | CDC (https://www.cdc.gov/ncbddd/autism/addm.html)

ATMega328P Microcontroller Pinout, Pin Configuration, Features & Datasheet (components101.com) (https://components101.com/microcontrollers/atmega328p-pinout-features-datasheet)

PROJECT | Scheme-it | Free Online Schematic and Diagramming Tool | DigiKey Electronics (https://www.digikey.in/schemeit/project/project-4053c3c6ebc149cd9ae47c63cc9c2e9f/)

CNC Shield V3 - Engraving Machine 3D Printer Expansion Board buy online at Low Price in India - ElectronicsComp.com (https://www.electronicscomp.com/cnc-shield-v3-3d-printer-a4988-expansion-board)

Arduino UNO + Arduino CNC Shield V3.0+A4988 Installation Guide « osoyoo.com (https://osoyoo.com/2017/04/07/arduino-uno-cnc-shield-v3-0-a4988/)

https://www.techopedia.com

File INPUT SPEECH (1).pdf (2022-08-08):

A very good evening to everyone present here , under the guidance of dr E vijayaragavan sir , I PUSHPAL DAS AND MY TEAM

MEMBERS , THE NAMES , ARE HONOURED TO PRESENT OUR IDEA FOR THE TOPIC TOYS FOR AUTISTIC KIDS

ABSTRACT

The main objective of our team is to make a toy for kids who suffer from autism , spectrum disorder , or autism, term used to

describe a group of neurodevelopmental conditions. Our team came by the resources , so according to specialists it has

been found that that , through out the ages of digital transforming world when it is an e learning platform and autism , a

proper output has not been observed as a result of it we actually could not predict whether the kid is getting addicted with

e learning materials or he/she is actually learning it, at the same time to deal with neurological problem we know that their

brain isn't mature enough for a gripping power , fine and motor problem , which is found in maximum autistic kids , which is a

neurological problem . Our team aim is to create an interface between a mechanism or a hardware with an e learning

software or application

PROBLEM STATEMENT

Neurological problem is observed in maximum autistic kids. The fine motor and the gross motor problem is what they suffer from.

Hence they find it difficult in writing , imagine how painful it is for an autistic kid to deal with such problem provide the case that they want to learn and write.

SOLUTION

what our team is trying to create a loop between the play and physicial therapy , resulting in a therapy to kids who have writing problem from their very childhood , kids who have difficulty to understand between 6 and 9 , b and d , the alphabetical order , a step from our team to make the basics strong and solve the neurological problem in kids.

As by the research we undergone and by the resources we can come to the point that autistic kid faces lots of problems with their sensory nerves and their gross motor and fine motor and so on. We are working on a project with an idea of making the kid to learn by making the kid to hold an artificial hand (robotic arm) or the mechanism as we said as the hardware , which has the ability to track the pattern of the letter and to guide the kid to move their hand in the right way to complete the pattern by interactive methods. Interactive methods will be the input given from the phone or the device where the mentor or the guide will download the application or the software from. And here We hope our idea would bring the changes in the kid positively.

ANALYSIS

- Our team have taken analysis of the project report into five major parts:
- Define
- Design
- Implement
- Analyze
- Share

We define our project as a major part or a revolution to bring a change for autistic kids having neurological problems. Not onely that our device completely focuses on the visual effect to make it more fascinating for the kid to make a contrast in its mind between a TLM and play. TLM is nothing but the teaching learning material .

About 1 in 54 children has been identified with autism spectrum disorder (ASD) according to estimates from CDC’s Autism and Developmental Disabilities Monitoring (ADDM) Network. About 1 in 6 (17%) children aged 3–17 years were diagnosed with a developmental disability, as reported by parents, during a study period of 2009-2017. These included autism, attention-deficit/hyperactivity disorder, blindness, and cerebral palsy, among others. As a target and a goal to achieve it is our duty to serve with the best possible technology as TLM to autistic kids.

## We designed our model My hand in a manner that it is fascinating enough and also will be used a learning material to make autistic kids write. When we talk about the design , we carried surveys. Our main key points by the respected

## authority of the autistic cares or school, was that to make it glow with colors and

comfortable for the kid to use it by its guide.

In our machine we need two users to control and learn from it. When I say control we are expecting a guide to input letters, words or numbers in the mobile phone. There by when the machine runs it writes A on the sheet of paper. As of now if we implement the idea it won't be fascinating to the kid to use it, but

there are visual effects too, there are two phases of this TLM, My hand.

## For example the mentor used the phone to select the letter 'A' , the kid follows the visuals and the animation on the e learning platform and later our machine

interface makes them write A with a single touch by the user.

Implementing the three things our team can surely change the vision of a CNC handwriting machine which is only made for purpose to print , but here we are connecting many dots together towards an environmental step in curing the neurological problem of an autistic kid , who have writing problem. When I say dots our team has brought a whole idea of CNC machine to reality to make it as a part of a toy and also as a teaching learning material ,which was very much recommended in the surveys , when we mentioned about the idea we are applying.

Thereby I share this particular contrast of a toy , where it can serve dual purpose and a visually fascinating thing for the kid to learn with it.

CONCLUSION

Finally, our team has come up with the conclusion that living in the 21st century where kids are born and brought up in the age of technologies and the digital world we must fix and deal with such challenging problems. Often people do have e-learning software but again, we fail to realize how it really affects the kids and also helps the kid to grow and evolve. Growth is a very essential part of life, and growing with just a digital interface is not what our duty is. Our duty is to make it efficient and worth the time and money they have spent on their development. We depict or define our machine or an artificial hand as a scope to neural science in future. We know that not only autistic kids but many people do face neurological problems where if they want to write they cannot do so but our machine the robotic hand will automatically create an impact on the disabled person. The combination of the concepts of Mechatronic and neuroscience will create a huge impact and make learning very easy for every person suffering from neurological problems. We create the future a place for great effortless learning and writing.

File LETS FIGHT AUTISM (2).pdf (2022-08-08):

# TOYS FOR


# AUTISTIC KIDS

# College Name


# SRM Institute of Science and Technology

Jadavpur University | Indian Institute of Engineering Science and Technology

NAME Dr E VIJAYARAGAVAN.

# PROFESSOR IN CHARGE


# EMAIL ID vijayare@srmist.edu.in

# DISCIPLINE Mechanical engineering

MOBILE | 9884214710


# Team member details

# TEAM MEMBER 1

NAME | Aryan N


EMAIL ID | panakalaryan@gmail.com
DISCIPLINE | CSE Cloud Computing
YEAR | 3rd year
MOBILE | 9978115598

# TEAM MEMBER 2

NAME | Abhishek Sarkar


EMAIL ID | abhisrkr007@gmail.com
DISCIPLINE | Electronics and

# telecommunication engineering

YEAR | 3rd year
MOBILE | 6290782054

# TEAM MEMBER 3

NAME | Suriya Devalan AR

EMAIL ID | as5539@srmist.edu.in
DISCIPLINE | Mechanical Engineering
YEAR | 3rd year
MOBILE | 8072137976

# TEAM MEMBER 4

NAME | Ahel Das Chatterjee


EMAIL ID | aheldc@gmail.com
DISCIPLINE | Department of Computer

# Science and Technology

YEAR | 3rd year
MOBILE | 8617791548

# TEAM MEMBER 5

NAME | Ved Prakash Dubey


EMAIL ID | dvedprakash2001@gmail.com
DISCIPLINE | CSE-SWE
YEAR | 3rd year
MOBILE | 9674990810

# TEAM MEMBER 6

NAME | Pushpal Das


EMAIL ID | pushpaldas2001@gmail.com
DISCIPLINE | Electronics and Communication

# Engineering

YEAR | 3rd year
MOBILE | 8910497557

# TEAM MEMBER 7

# NAME Santhosh Kumar. R


EMAIL ID | klt.santhosh2002@gmail.com
DISCIPLINE | Electronics and

# Communication Engineering

YEAR | 3rd year
MOBILE | 9677867812

# ABSTRACT


P
R


O
B
L
E
M

# STATEMENT


# SOLUTION

W
O


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
# Click to add text Click to add text

# HARDWARE

# WORKINGMODELS


# WORKINGMODEL


# WORKINGMODEL


# SYSTEMDIAGRAM


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
# Click to add text Click to add text

# SOFTWARE

W
O


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
# Click to add text Click to add text

# FRONT-END

W
O


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
# Click to add text Click to add text

# BACK-END


D
E
S
I
G
N

# CONSTRAINTS

C
O
S
T

# ESTIMATION

PRODUCT NO | PRODUCT NAME | PRODUCTION COST (in Rs) | RESEARCH COST (in Rs)
1 | Servo motor | 50-100 | 220-400
2 | Stepper motor | 150-300 | 500-600
3 | HC-05 Bluetooth Mo dule | 100-150 | 400-500
4 | L239 CNC shield for Arduino | 100 | 300
5 | Arduino UNO R3 | 200-300 | 500-800
6 | Radial bearings | 150-200 | 400-500
7 | Smooth rods | 100-250 | 400-600
PRODUCT NO | PRODUCT NAME | PRODUCTION COST (in Rs) | RESEARCH COST (in Rs)
1 | Thread rods | 250-400 | 1000
2 | Linear motion ball bearing | 300 | 600-700
3 | Coupling | 100-150 | 329
4 | Jumper wires | 50 | 100-150
6 | Power switch | 100 | 150
7 | Power source | 500 | 1400


# ANALYSIS



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
# Predicted model

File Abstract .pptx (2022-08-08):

## TOYS FOR AUTISTIC KIDS


## College Name

SRM Institute of Science and Technology
Jadavpur University

## Faculty guide details

NAME Dr E VIJAYARAGAVAN.
EMAIL ID vijayare@srmist.edu.in .
DISCIPLINE Mechanical Engineering.
YEAR Not applicable.
MOBILE 9884214710.

## Team member details

Large skydiving group mid-air

## TEAM MEMBER 1

NAME Pushpal Das .
EMAIL ID pushpaldas2001@gmail.com .
DISCIPLINE Electronics and Communication Engineering .
YEAR 3rd year .
MOBILE 8910497557 .

## TEAM MEMBER 2

NAME Abhishek Sarkar.
EMAIL ID abhisrkr007@gmail.com .
DISCIPLINE Electronics and Teleommunication Engineering.
YEAR 3rd year.
MOBILE 6290782054.

## TEAM MEMBER 3

NAME Santhosh Kumar. R.
EMAIL ID klt.santhosh2002@gmail.com .
DISCIPLINE Electronics and Communication Engineering.
YEAR 3rd year.
MOBILE 9677867812.

## TEAM MEMBER 4


NAME Suriya Devalan AR.
EMAIL ID as5539@srmist.edu.in.
DISCIPLINE Mechanical Engineering.
YEAR 3rd year.
MOBILE 8072137976

## AUTISM

Autism spectrum disorder , or autism, is a broad term used to describe a group of neurodevelopmental conditions.
These conditions are characterized by differences in communication and social interaction.
People with ASD often demonstrate restricted and repetitive interests or patterns of behaviour.
ASD is found in people around the world, regardless of race and ethnicity, culture, or economic background.
A study of 8-year-olds in 11 locations throughout the United States found a 4.3 to 1 boy-to-girl ratio Trusted Source in.

## CAUSES OF AUTISM

having an immediate family member who’s autistic.
genetic mutations.
fragile X syndrome and other genetic disorders.
being born to older parents.
low birth weight.
metabolic imbalances.
exposure to heavy metals and environmental toxins.
a history of viral infections.
fatal exposure to the medications valproic acid or thalidomide.

## TREATMENT

behavioural therapy.
play therapy.
occupational therapy.
physical therapy.
speech therapy.

## TREATMENT

- Massages, weighted clothing and blankets and meditation techniques, may also help some autistic people manage symptoms.

## AWARENESS

April 2 is World Autism Awareness Day April has also become known as Autism Awareness Month in the United States.
However, many community advocates have rightly called for the need to increase awareness about ASD year-round, and not just during 30 select days.
The Autism Society of America and other advocates have even proposed that April be designated Autism Acceptance Month instead.

## AUTISM ON KIDS

Autistic children may not reach the same developmental milestones as their peers, or they may demonstrate the loss of previously developed social or language skills.
Autistic children may also engage in repetitive behaviours, have difficulty sleeping or compulsively eat non-food items.
Many resources are available to help autistic children as well as their loved ones.
Local support groups can be found through the national non-profit The Autism Society of America

## RESOURCES

Graph on document with pen

Name of the organization | Spokesperson | Contact number
Sunshine Autism Care. | Nilanjana Rambothu | +91 98318 29177
Happy to learn autism. | Susmita Das Bhattacharya | +918017784551
Special educator for special child. | Pijush Ray | +917980171377
Jadavpur Manogyan Rehabilitation Programme for Disabled Children. | Iti Saha | +919836430248
Kolkata Anubhuti. | Gopa Mukherjee | +919674340287

- Our team would like to acknowledge the following organizations for their ample amount of time they have contributed for collecting data and information for our observatory and experiment purposes .

## Questions asked What are the problems faced on this particular disease, autism?

“The brain isn't mature as a result grasping power, gross motor and fine motor is not properly developed. As a result, basic activities such as holding a pencil, scribbling, dot joining etc. becomes difficult for them to perform. As a result, writing skill isn't properly developed.
Autism can be due to a number of reasons, pregnancy stress of the mother, or pressure on the brain during delivery etc.”
“ In many cases fine motor problem is widely observed among the majority kids with autism. For example, problem in how to hold a pencil is a common issue noticed among such kids. In some cases, kids with autism find it difficult to quickly follow or execute instructions. With age, the child might develop speech problems. A common characteristic noticed among these children that they are antisocial and love their own company, they prefer solitude.”
“In this condition the children suffer Neuro problem due to which they have issue in gripping objects (pen, pencil etc.) and hence they face difficulty in writing. They face fine motor problem and gross motor problem.”

## Questions asked What is the range of age group being affected to this particular problem?

“Inborn”
“Pijush Ray and his team have observed that autism is not only inborn but can also develop after certain age. For example, there are cases where a child develops the condition after 7 to 8 years of age.”
“Inborn, autism can be detected even within six months of birth. With age there can be onset of speech issues.”

## Questions asked Opinions on the change for improving an autistic kid vision and reading problems.

“Counselling, physically helping them to grip objects and use them. Massaging the hands and fingers, use of some sensory stimuli such as sandpaper to improve the grasping power. These help in improving this condition to some level.”
“Lifelong support”
“Audio visual aids help the children understand topics and instructions in a better and easier way.”

## Questions asked How can a robotic hand would meet the contrast of attraction between a kid with autism and a toy, what makes it more attractive for the kid to work on it?

“The things to be kept in mind while making the TML (teaching learning material) is that it should be low cost and sturdy device. It should be visually appealing with the use of audio, if possible, to grow interest among the autistic kids. Inputting audio aid(music)”
“Visually appealing, with lights and colours would be interesting for these children. (Very important for their eye contact)
“Visual inputs such as lighting in the device can be interesting to them. Also using audio can help them understand and find it interesting.”
These kids are sensitive towards touch, hence adding different textures (soft texture, rough texture) for them to feel/touch would help them get fascinated and interested.”

## A C K N O W L E D G E M E N T

- We specially thank, Nilanjana Rambothu , Founder and Director of Sunshine Autism Care and consultant RCI holder in Special education (ASD) , for the time she has contributed on this project.

## GRAPHICAL ANALYSIS


- Trends over time in the number of children with autism according to the IDEA.

## GRAPHICAL ANALYSIS


- Trends over time in the number of children with autism according to the IDEA.

## GRAPHICAL ANALYSIS


- Prevalence of autism and parentally reported.

## GRAPHICAL ANALYSIS


- Prevalence of Autism Increases by 10%, to 1 in 54 Children | Southwest Autism Research & Resource Center.

## GRAPHICAL ANALYSIS

- Neurotypical Peers are Less Willing to Interact with Those with Autism based on Thin Slice Judgments | Scientific Reports.


## GRAPHICAL ANALYSIS


- Graph showing the percentage of the sample from Study 1 with and without reported talents, or ''Special Isolated Skills'' , in any domain and in each of the six ADI-R SIS domains separately.

## GRAPHICAL ANALYSIS

- Impact of mainstream classroom setting on attention of children with autism spectrum disorder: an eye-tracking study | SpringerLink.


## C O N C L U S I O N

- As by the research we undergone and by the resources we can come to the point that autistic kid faces lots of problems with their sensory nerves and their gross motor and fine motor and so on. We are working on a project with an idea of making the kid to learn by making the kid to hold an artificial hand (robotic arm) which has the ability to track the pattern of the kid’s hand movement and to guide the kid to move their hand in the right way to complete the pattern by interactive methods. We hope our idea would bring the changes in the kid positively.

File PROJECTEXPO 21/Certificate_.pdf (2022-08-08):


## Pushpal Das

Toys for Autistic Kids.

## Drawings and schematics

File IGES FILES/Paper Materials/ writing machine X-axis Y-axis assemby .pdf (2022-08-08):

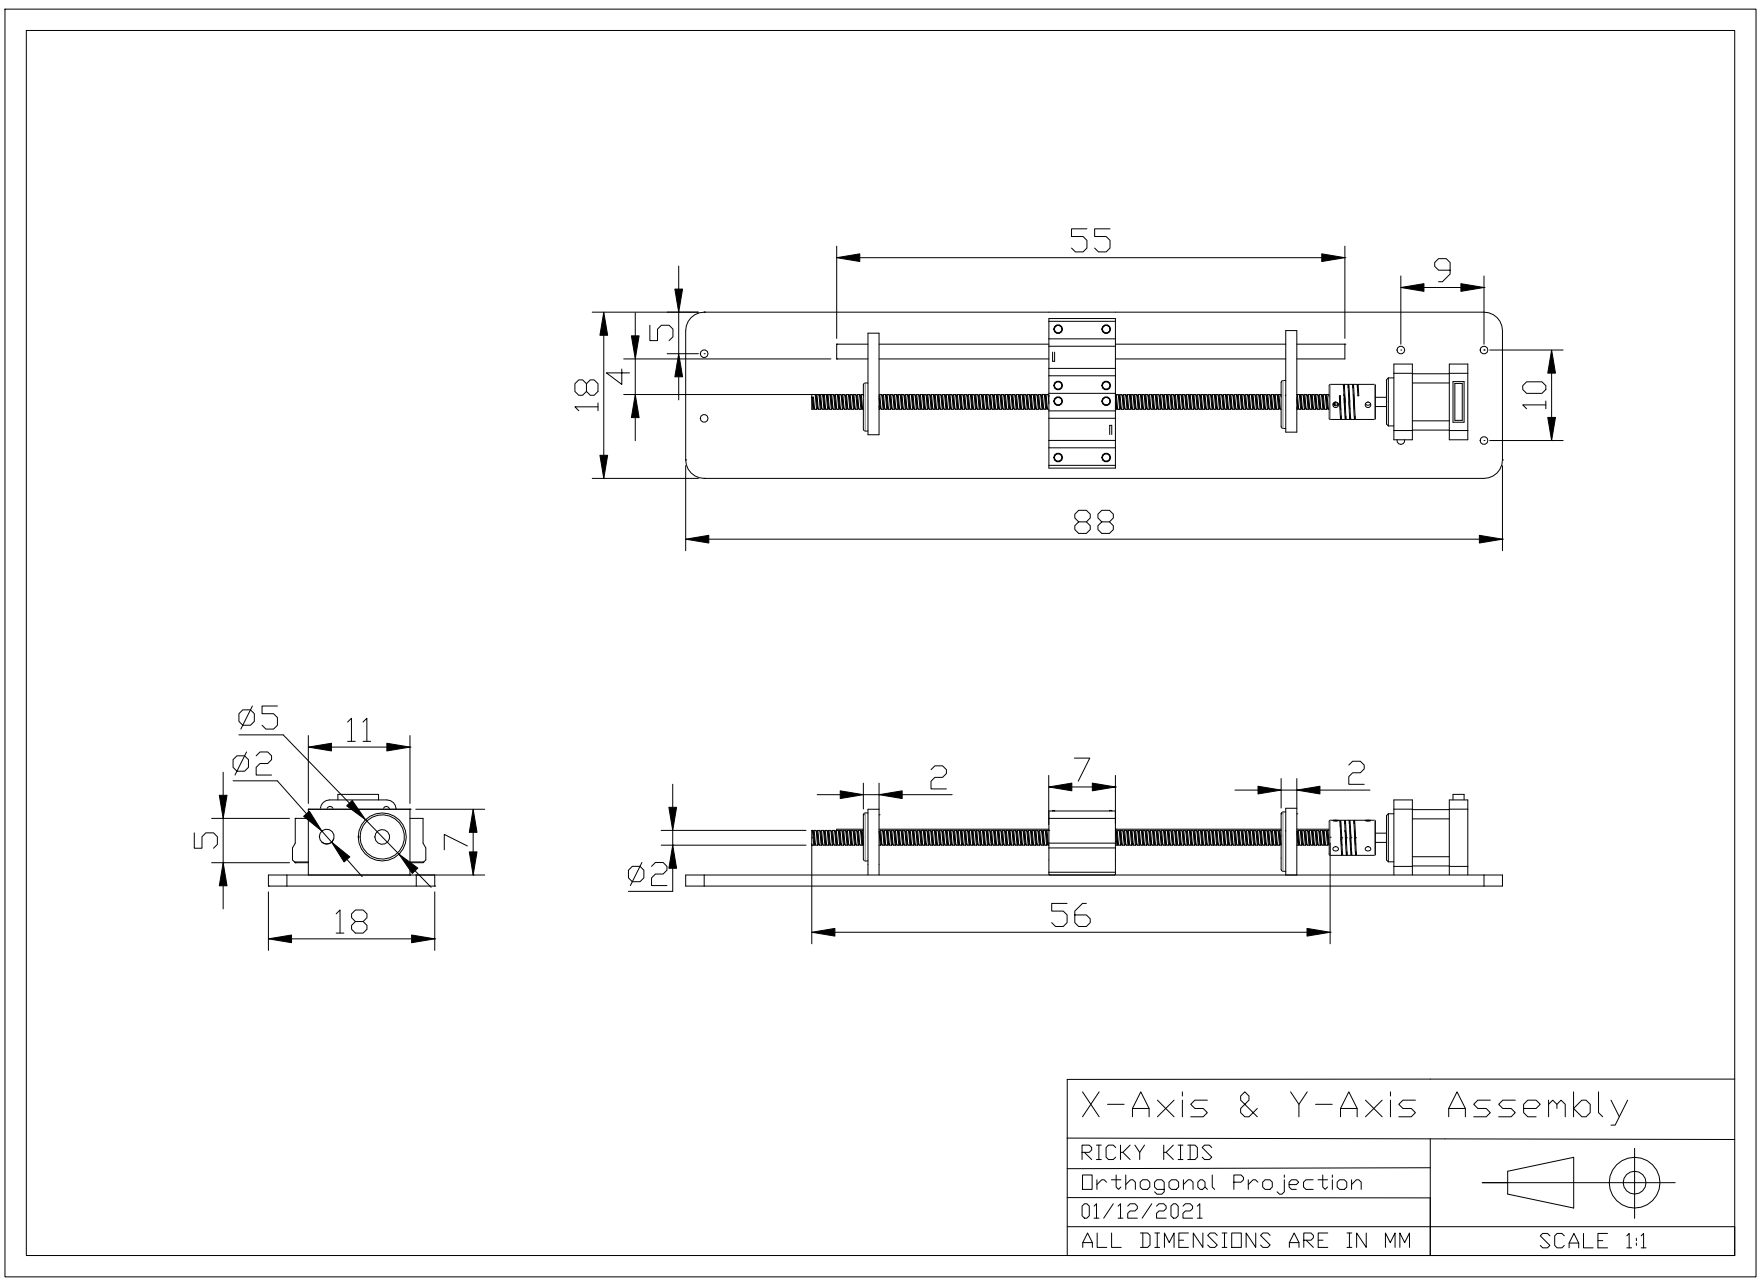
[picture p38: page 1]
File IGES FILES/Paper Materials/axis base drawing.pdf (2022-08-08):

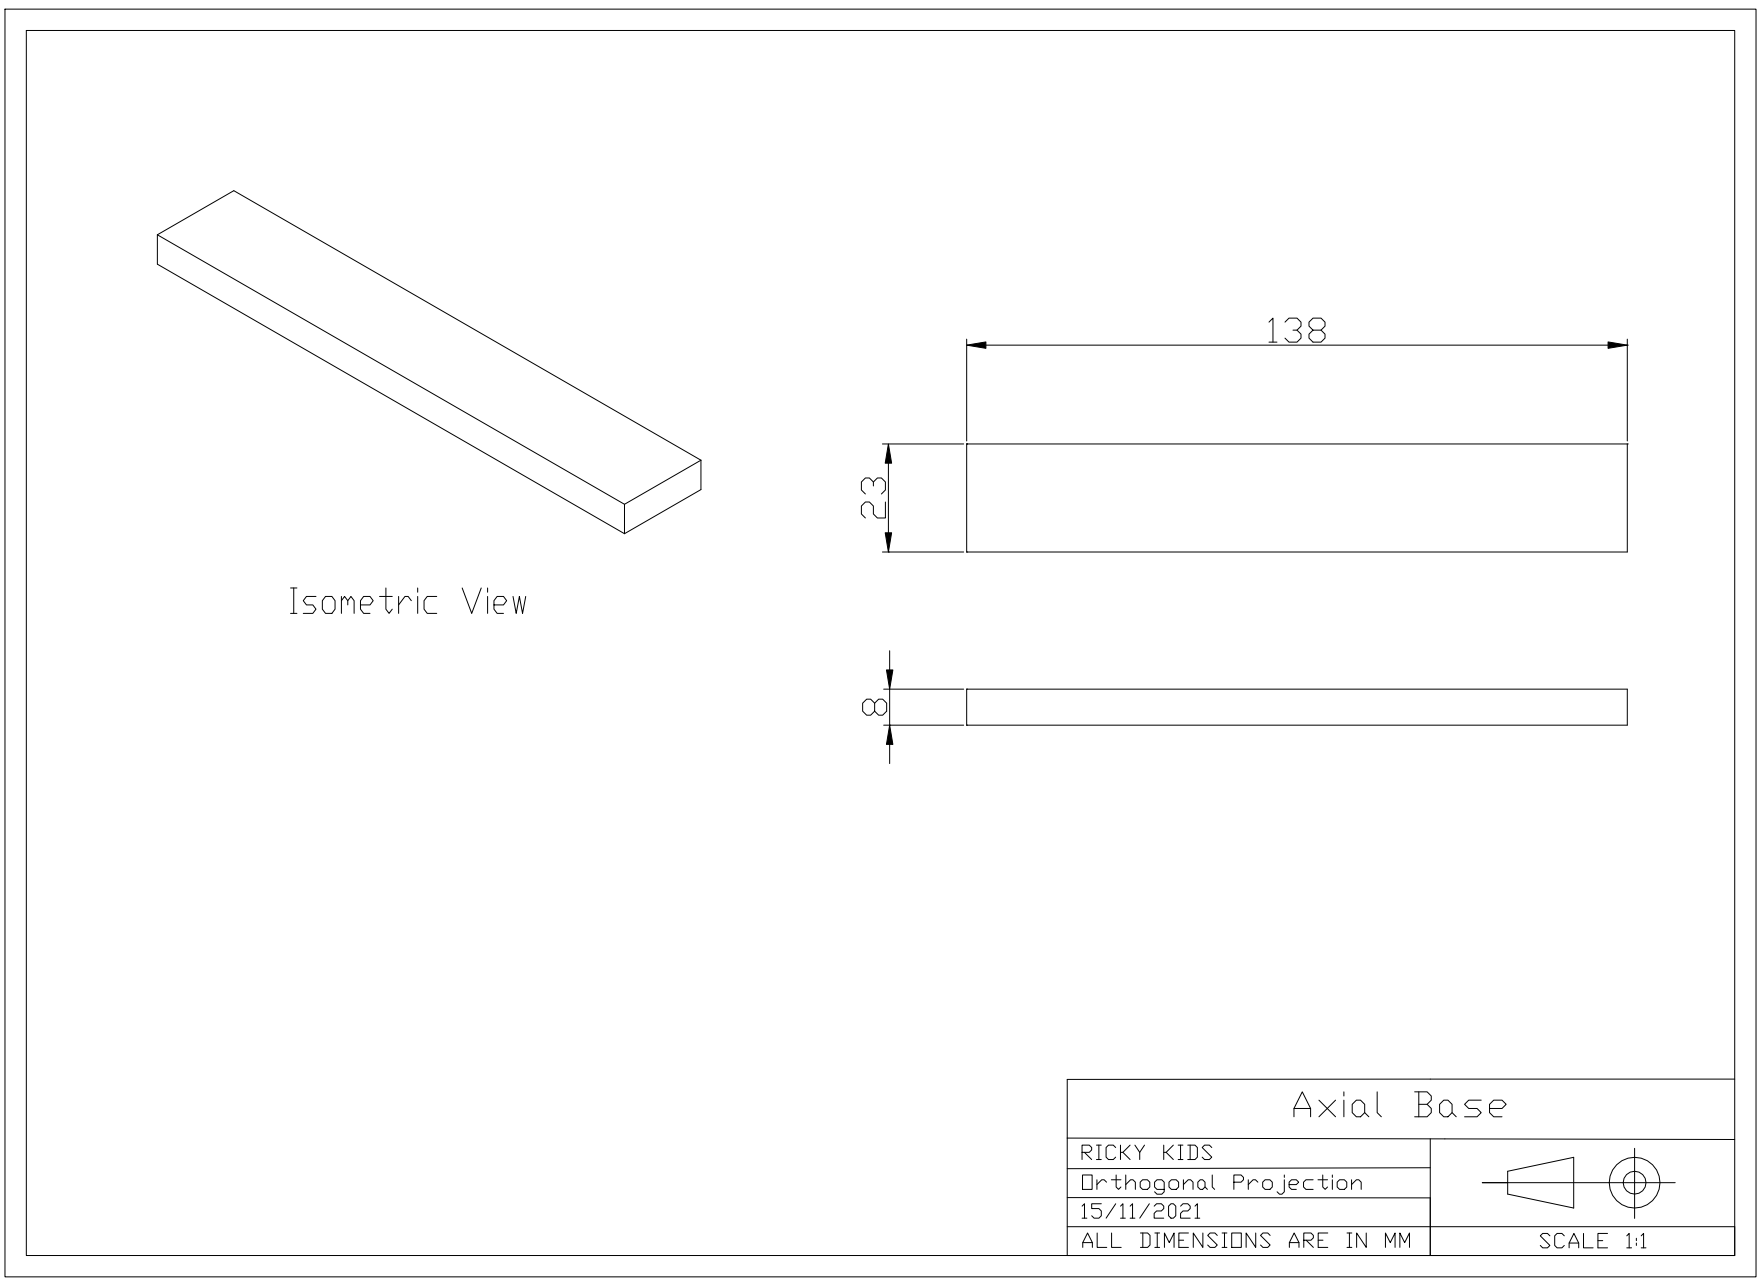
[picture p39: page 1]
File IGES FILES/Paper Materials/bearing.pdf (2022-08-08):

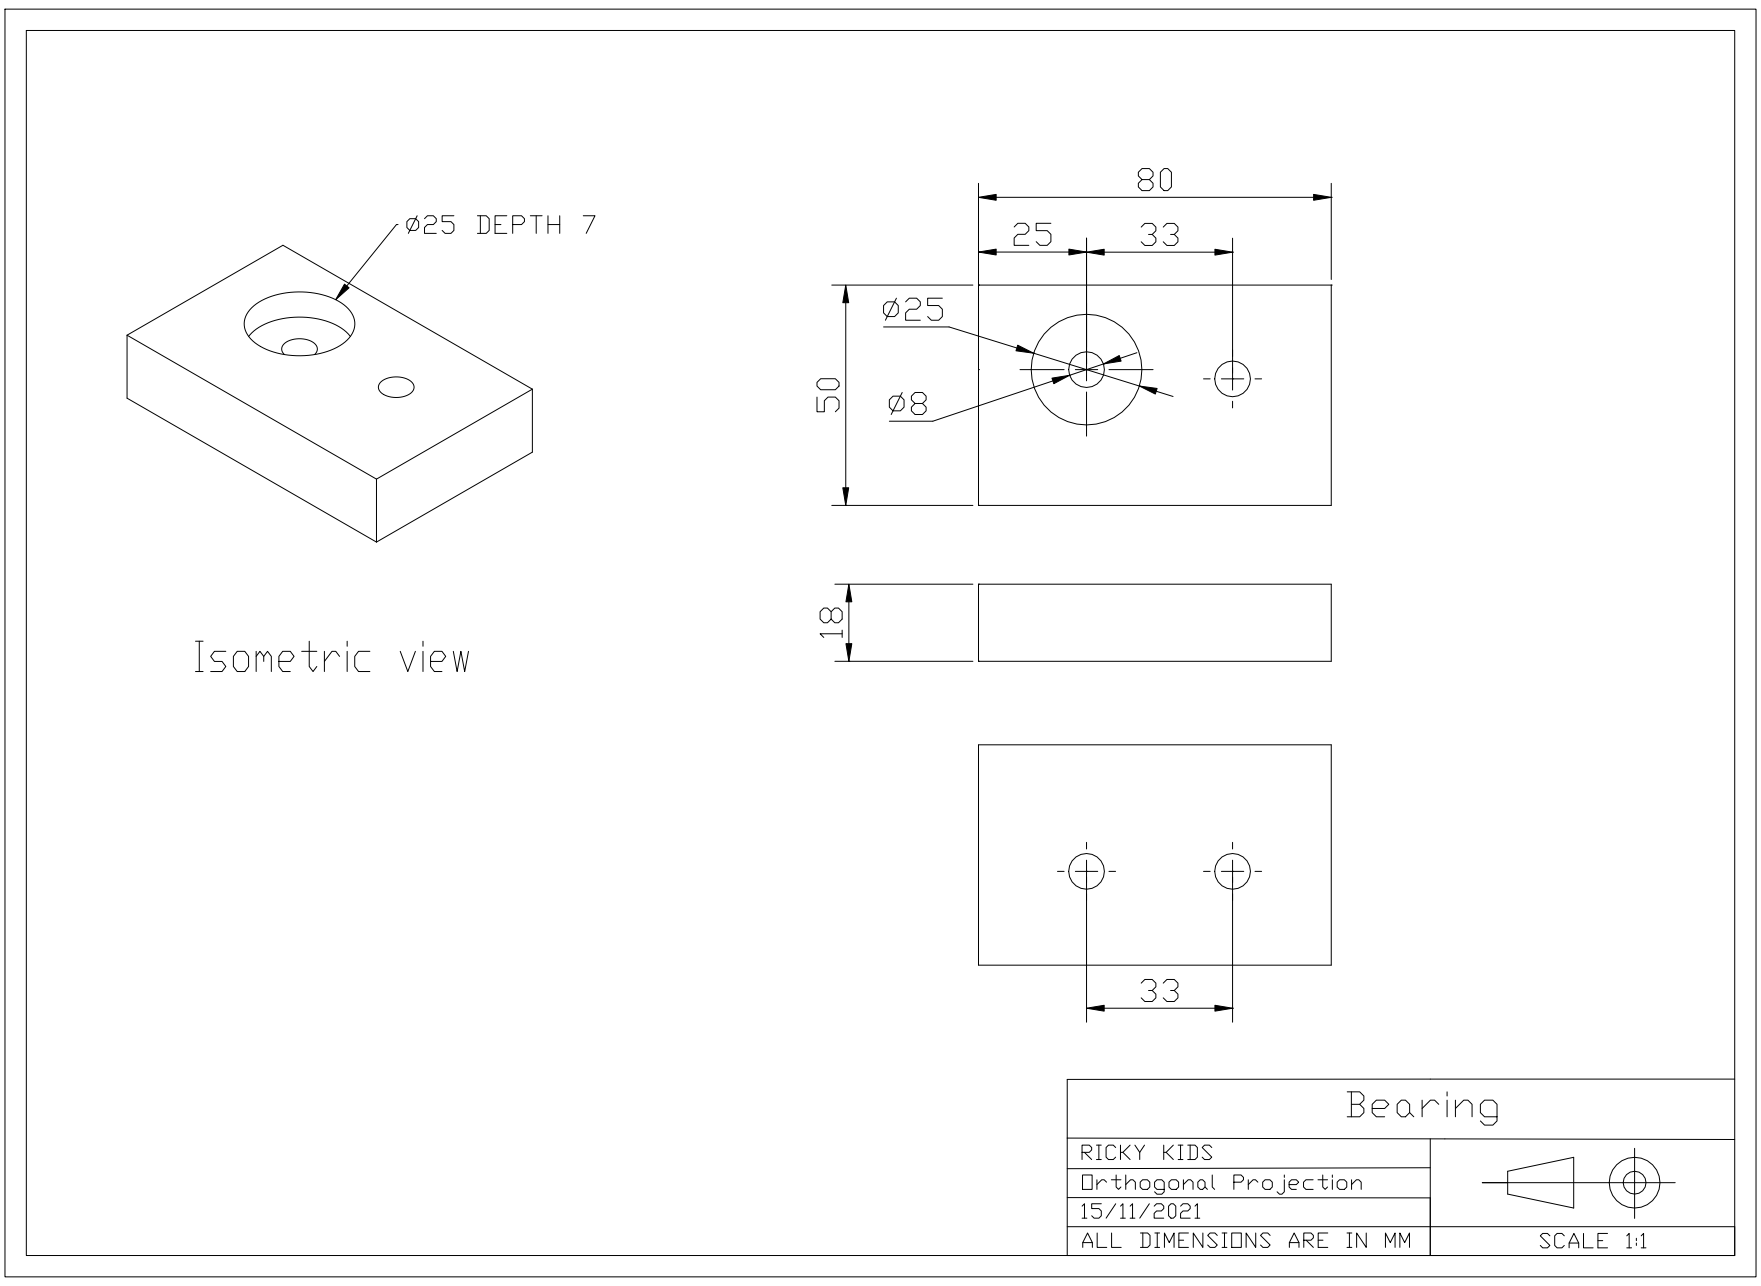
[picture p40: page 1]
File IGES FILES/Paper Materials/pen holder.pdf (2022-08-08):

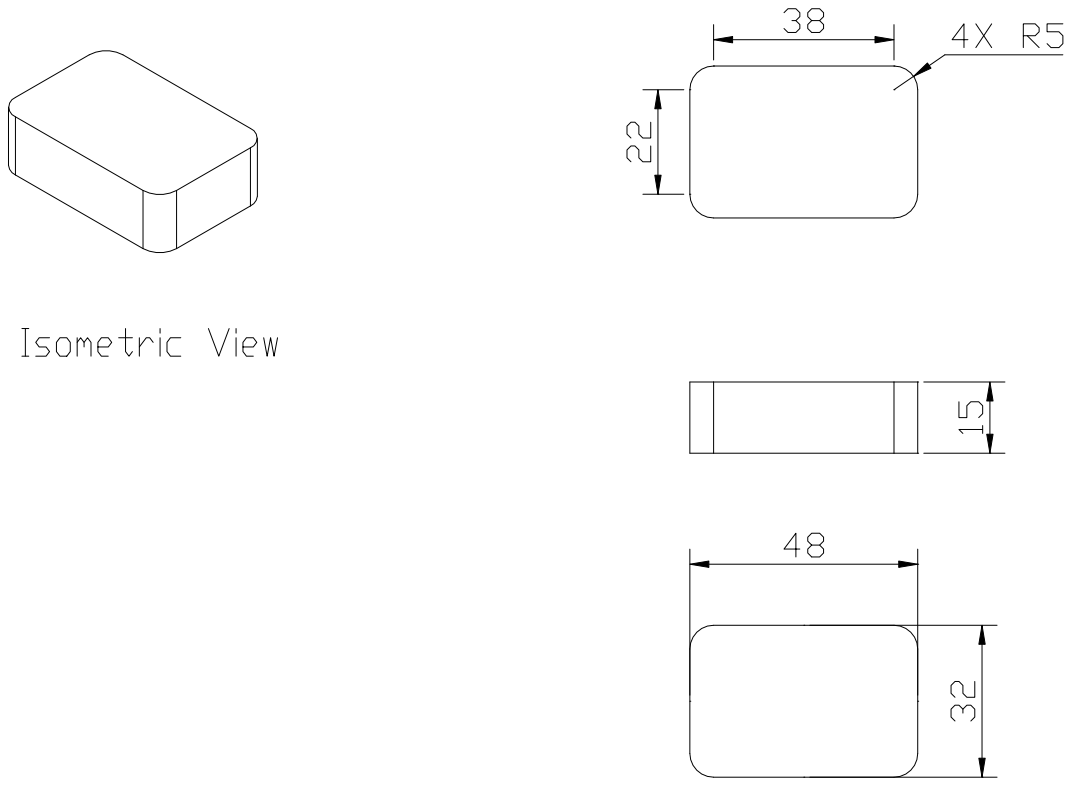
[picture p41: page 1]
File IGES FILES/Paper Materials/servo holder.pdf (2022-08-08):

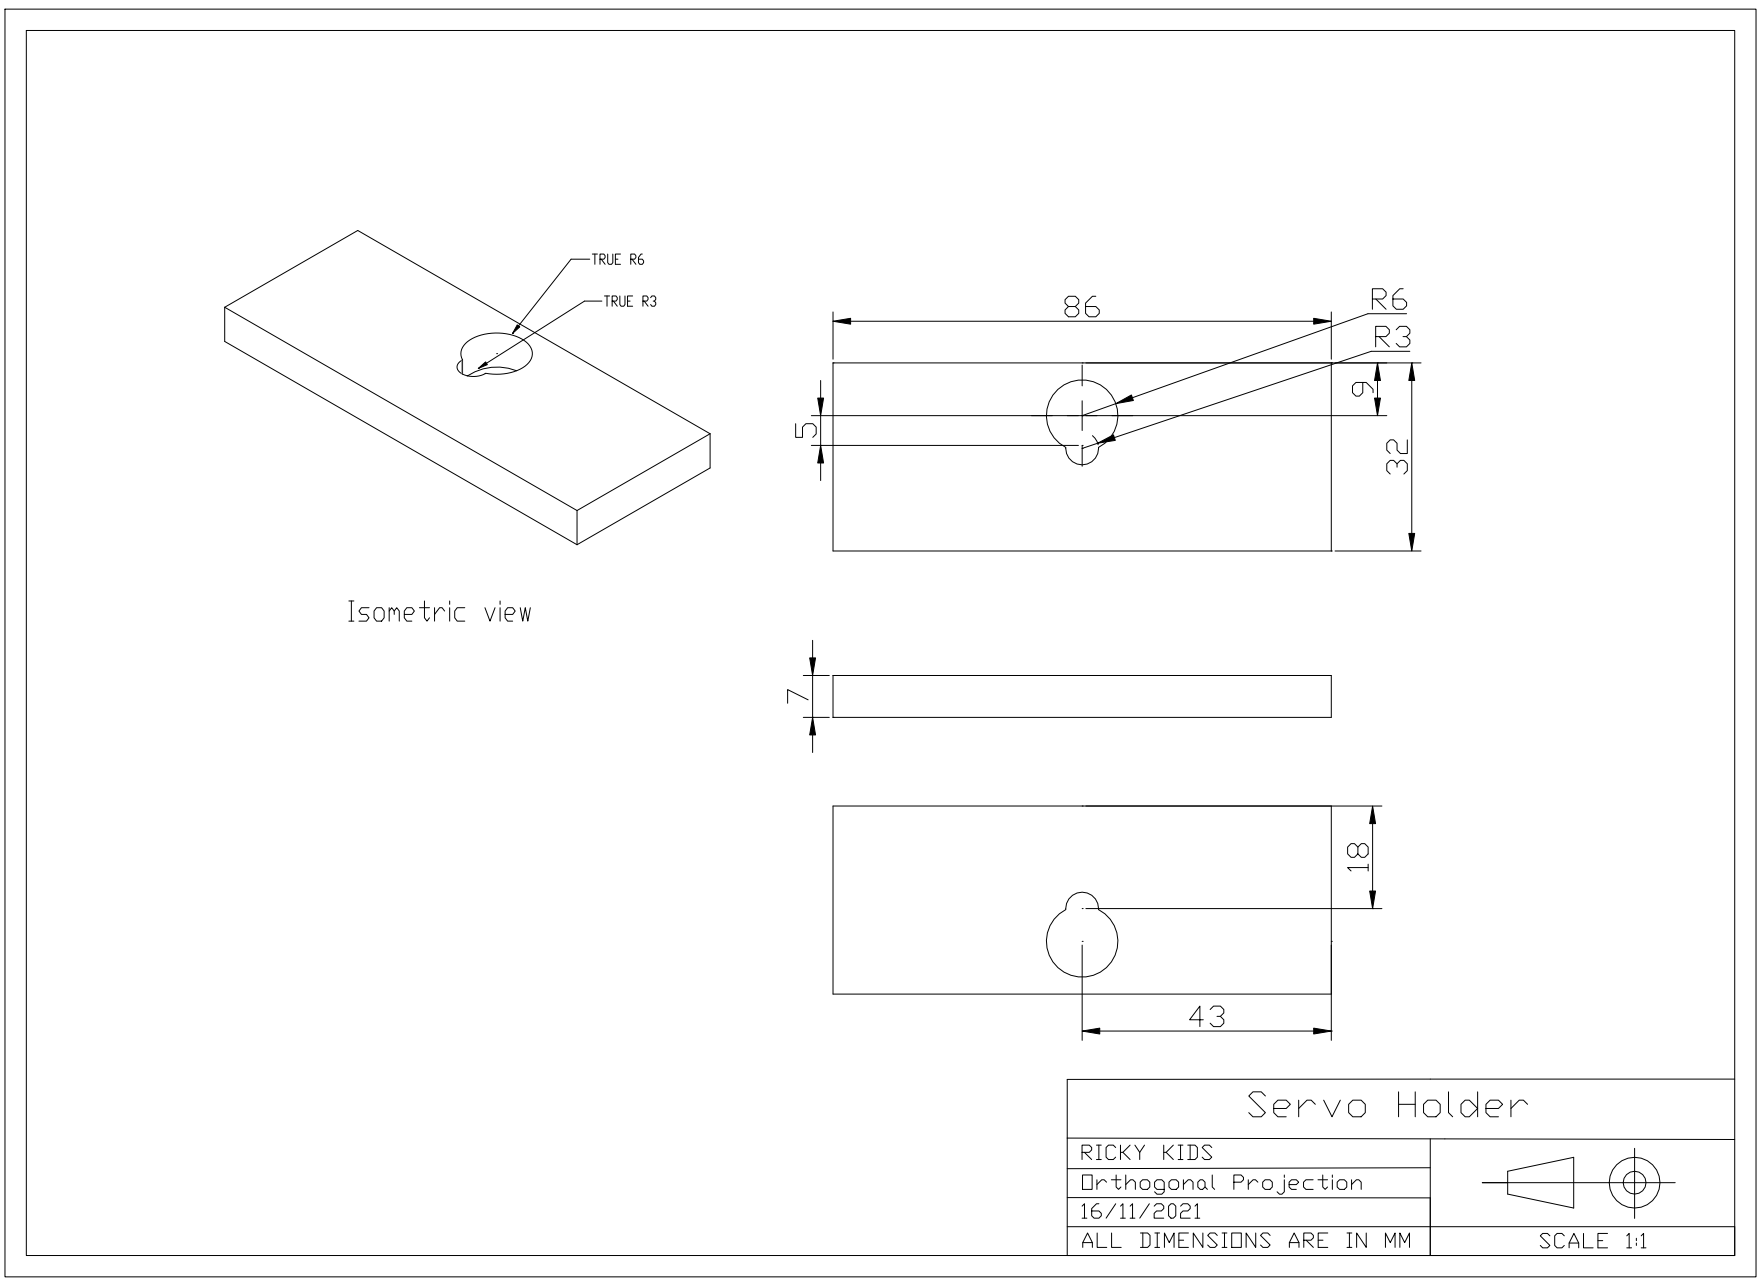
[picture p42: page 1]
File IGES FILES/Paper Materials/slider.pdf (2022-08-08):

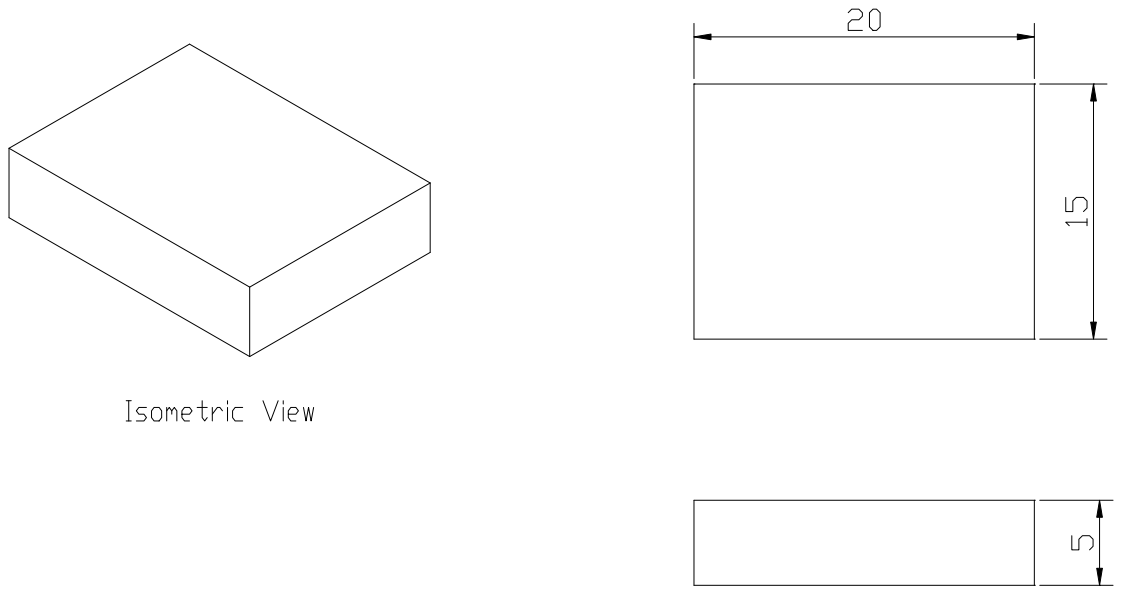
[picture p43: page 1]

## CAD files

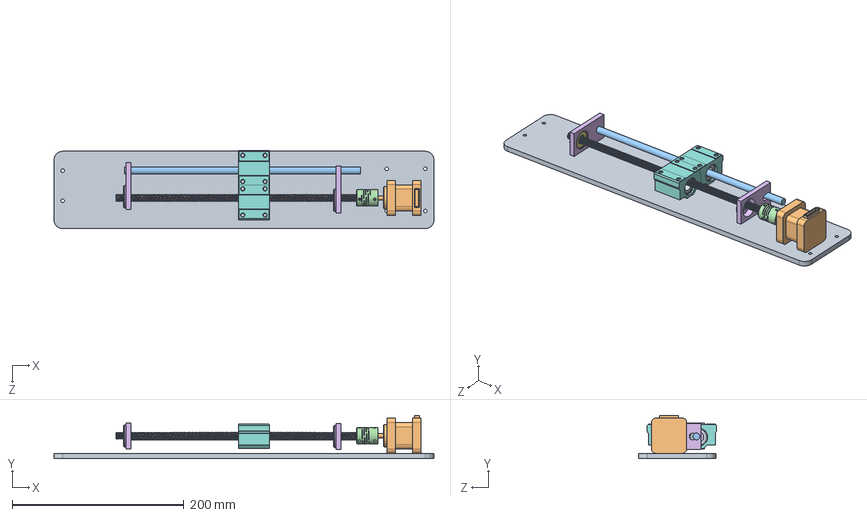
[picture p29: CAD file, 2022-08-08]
IGES FILES/DIY writing machine y-axis assemby.SLDASM
442.0 x 50.1 x 91.0 mm
buttom plate
Stepper motor NEMA17
linear shaft 08 diameter
coupling as 5-8
threaded rod
bearing holder 2 x 2
Bearig 8x22x7
basic internal retaining ring_ai x 4

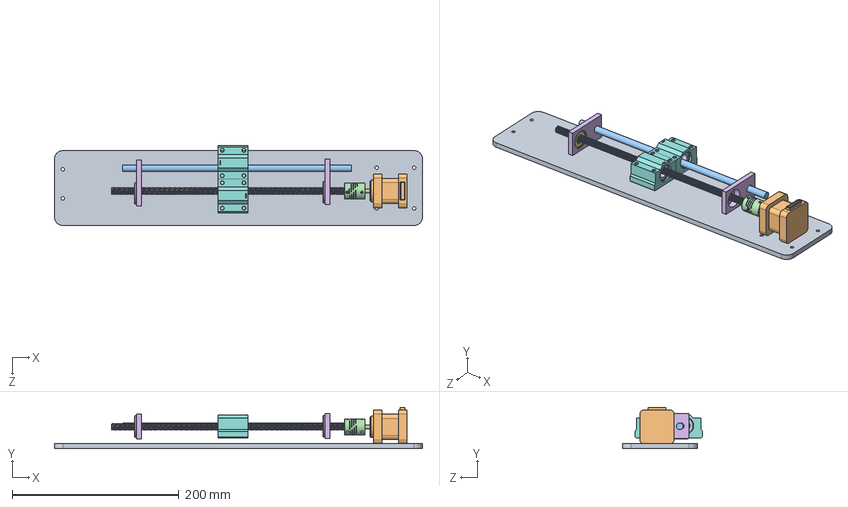
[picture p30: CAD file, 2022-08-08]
IGES FILES/DIY writing machine X-axis assemby.SLDASM
442.0 x 49.7 x 96.1 mm
buttom plate
Stepper motor NEMA17
linear shaft 08 diameter
coupling as 5-8
threaded rod
bearing holder 2 x 2
Bearig 8x22x7
basic internal retaining ring_ai x 4

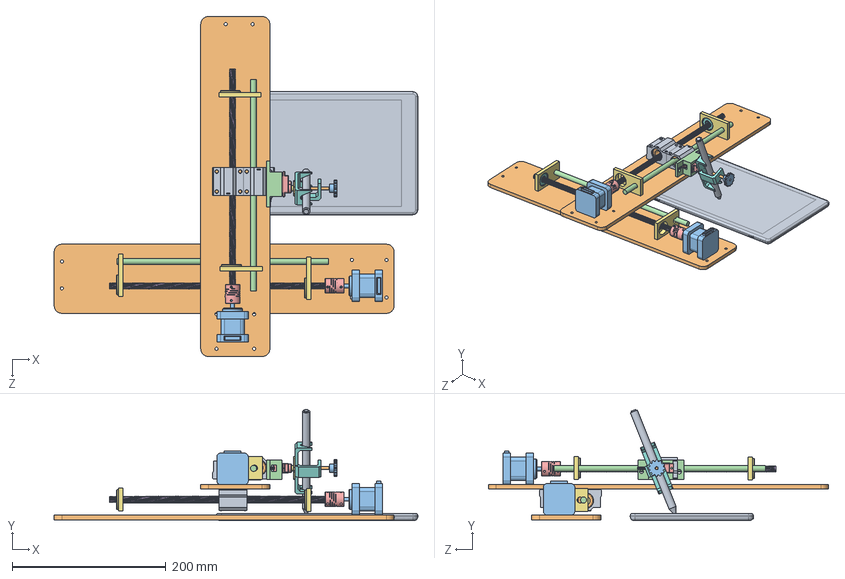
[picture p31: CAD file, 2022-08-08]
IGES FILES/only model.SLDASM
472.8 x 144.5 x 442.0 mm
Kindle_Fire_HD_10_Gen7.step
buttom plate x 2
Stepper motor NEMA17 x 2
linear shaft 08 diameter x 2
coupling as 5-8 x 2
threaded rod x 2
bearing holder 2 x 4
Bearig 8x22x7 x 2
basic internal retaining ring_ai x 8
Servo motor mounted
Servo Motor
cr flat head screw_is
Servo Arm
Pen cliper
pen
socket head cap screw_am
pen cliper mounted

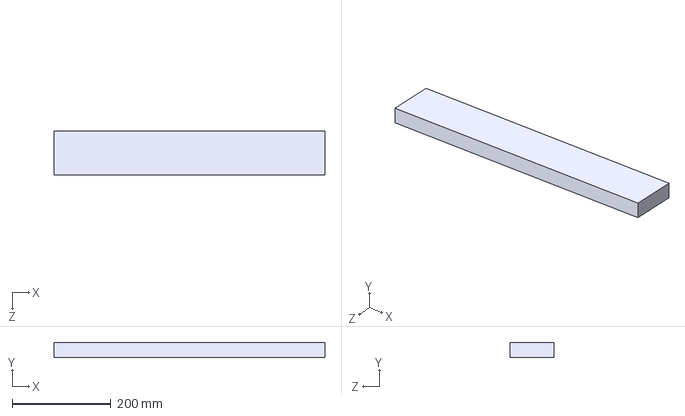
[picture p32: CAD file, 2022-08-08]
IGES FILES/axis base.IGS
550.0 x 30.0 x 90.0 mm

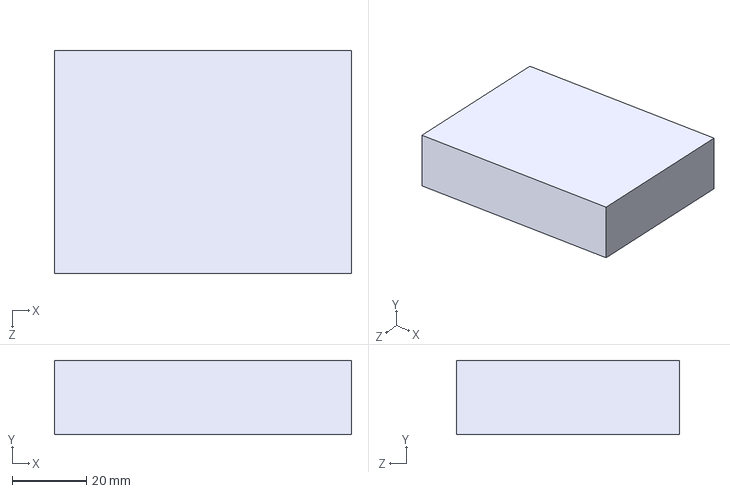
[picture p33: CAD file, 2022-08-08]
IGES FILES/slider.IGS
80.0 x 20.0 x 60.0 mm

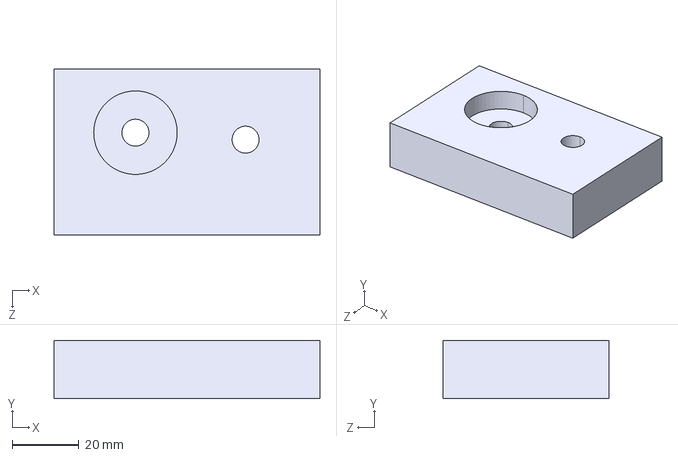
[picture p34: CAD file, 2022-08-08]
IGES FILES/printing part1.IGS
80.0 x 17.5 x 50.0 mm

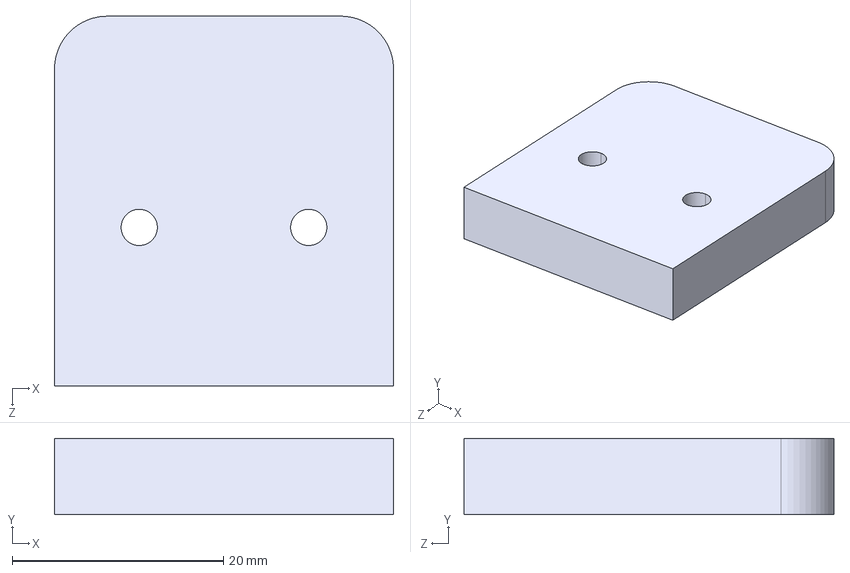
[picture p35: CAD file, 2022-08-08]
IGES FILES/printing part4.IGS
32.1 x 7.20 x 35.0 mm

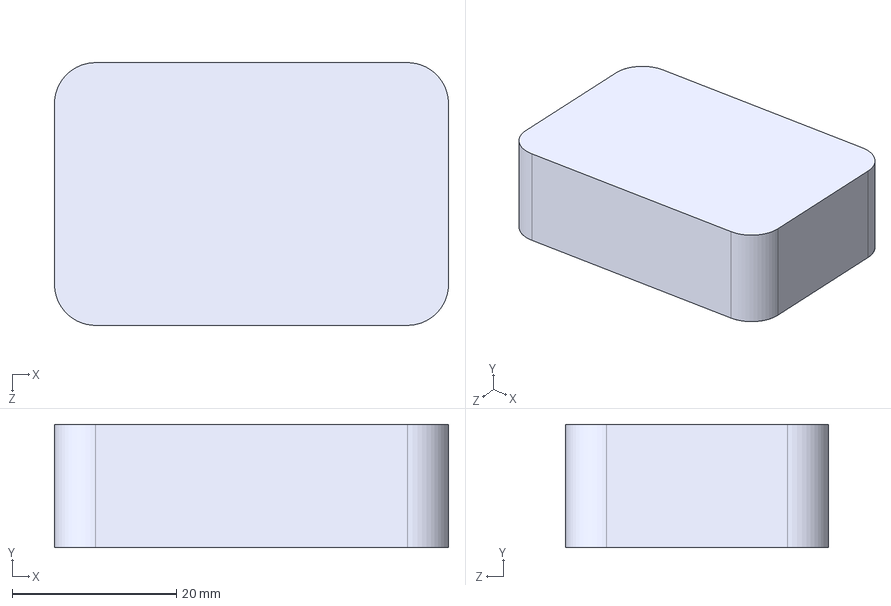
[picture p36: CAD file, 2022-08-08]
IGES FILES/printing part3.IGS
48.0 x 15.0 x 32.0 mm

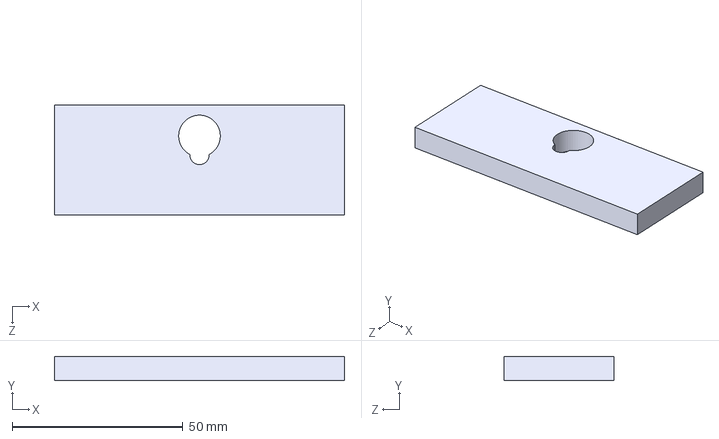
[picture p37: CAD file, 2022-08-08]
IGES FILES/printing part2.IGS
85.0 x 7.15 x 32.1 mm
